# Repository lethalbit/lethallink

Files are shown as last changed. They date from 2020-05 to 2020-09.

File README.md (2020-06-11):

# lethallink

lethallink is a PCI-Express DMA engine with on board debugging machinery designed in an attempt to allow for mostly transparent access to a system under test with no software at all running on said system.

All of the information is exfiltrated onto a control system that can then be used for analysis. The control system can also interact with lethallink to add things like memory watchpoints via the control software or GDB integration. 

## Licenses

The lethallink project is licensed under 3 individual licenses, one for the hardware and gateware, one for the software and one for the documentation.

The hardware and gateware are licensed under the [CERN-OHL-S](https://ohwr.org/cern_ohl_s_v2.txt), the license for which can be found in [LICENSE.hardware](LICENSE.hardware) and [LICENSE.gateware](LICENSE.gateware).

The software is licensed under the BSD-3-Clause and can be found in [LICENSE.software](LICENSE.software).

The documentation is licensed under the Creative Commons [CC-BY-SA](https://creativecommons.org/licenses/by-sa/2.0/) and can be found in [LICENSE.docs](LICENSE.docs)

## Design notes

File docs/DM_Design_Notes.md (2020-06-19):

# Debug Module (DM) Daughtercard Design Notes

**NOTE:** These notes are the WIP version of the specification for lethallink Debug Module (DM) interface, for the version that is released and shipped for each revision of the board, consult the appropriate reference manual.

## Abstract

Do to the difficulty in providing an "all-in-one" solution that is flexible enough to allow to the low-level interfacing to machines, it has been decided that most of the architecture specific hardware to a daughtercard using a modified DDR4 SODIMM 260 pin format.

This allows for a substantial amount of IO and power to be provided to the daughtercard. Enabling a proper high-speed bus between the main system FPGA and any of the on-board machinery for data transport and a QSPI control channel for management and configuration.

## Electromechanical Specification

The electromechanical specification for the DM daughtercards follows much of normal specification for a DDR4 SODIMM with 260 positions, however it is longer and has a mounting hole for two `8mm` tall `M3` standoffs.

It's rough dimensions are `80mm` long by `69.60mm` wide, with the two `M3` mounting holes `4.5mm` from the side and bottom of each corner.

Below you can see a sketch of the profile for the daughtercards:

**NOTE:** This drawing is not to scale, for a to-scale drawing with all the measurements see the SolveSpace CAD files in the [`docs/cad/`](../docs/cad/) directory. Alternatively, you can inspect the [lethallink KiCad library](../docs/eda) where there is a footprint and schematic part. Or, lastly, use inspect one of the [debug modules](../hardware/boards), or use the [debug module template KiCad project](../hardware/boards/template_dm).

<p align="center">
  
</p>

### Pinout

The following is a table of the pinout for the debug module:

| PIN # | PIN NAME | PIN # | PIN NAME | PIN # | PIN NAME |
|---|---|---|---|---|---|
| `001` | `TODO NO SPEC` | `002` | `TODO NO SPEC` | `003` | `TODO NO SPEC` |
| `004` | `TODO NO SPEC` | `005` | `TODO NO SPEC` | `006` | `TODO NO SPEC` |
| `007` | `TODO NO SPEC` | `008` | `TODO NO SPEC` | `009` | `TODO NO SPEC` |
| `010` | `TODO NO SPEC` | `011` | `TODO NO SPEC` | `012` | `TODO NO SPEC` |
| `013` | `TODO NO SPEC` | `014` | `TODO NO SPEC` | `015` | `TODO NO SPEC` |
| `016` | `TODO NO SPEC` | `017` | `TODO NO SPEC` | `018` | `TODO NO SPEC` |
| `019` | `TODO NO SPEC` | `020` | `TODO NO SPEC` | `021` | `TODO NO SPEC` |
| `022` | `TODO NO SPEC` | `023` | `TODO NO SPEC` | `024` | `TODO NO SPEC` |
| `025` | `TODO NO SPEC` | `026` | `TODO NO SPEC` | `027` | `TODO NO SPEC` |
| `028` | `TODO NO SPEC` | `029` | `TODO NO SPEC` | `030` | `TODO NO SPEC` |
| `031` | `TODO NO SPEC` | `032` | `TODO NO SPEC` | `033` | `TODO NO SPEC` |
| `034` | `TODO NO SPEC` | `035` | `TODO NO SPEC` | `036` | `TODO NO SPEC` |
| `037` | `TODO NO SPEC` | `038` | `TODO NO SPEC` | `039` | `TODO NO SPEC` |
| `040` | `TODO NO SPEC` | `041` | `TODO NO SPEC` | `042` | `TODO NO SPEC` |
| `043` | `TODO NO SPEC` | `044` | `TODO NO SPEC` | `045` | `TODO NO SPEC` |
| `046` | `TODO NO SPEC` | `047` | `TODO NO SPEC` | `048` | `TODO NO SPEC` |
| `049` | `TODO NO SPEC` | `050` | `TODO NO SPEC` | `051` | `TODO NO SPEC` |
| `052` | `TODO NO SPEC` | `053` | `TODO NO SPEC` | `054` | `TODO NO SPEC` |
| `055` | `TODO NO SPEC` | `056` | `TODO NO SPEC` | `057` | `TODO NO SPEC` |
| `058` | `TODO NO SPEC` | `059` | `TODO NO SPEC` | `060` | `TODO NO SPEC` |
| `061` | `TODO NO SPEC` | `062` | `TODO NO SPEC` | `063` | `TODO NO SPEC` |
| `064` | `TODO NO SPEC` | `065` | `TODO NO SPEC` | `066` | `TODO NO SPEC` |
| `067` | `TODO NO SPEC` | `068` | `TODO NO SPEC` | `069` | `TODO NO SPEC` |
| `070` | `TODO NO SPEC` | `071` | `TODO NO SPEC` | `072` | `TODO NO SPEC` |
| `073` | `TODO NO SPEC` | `074` | `TODO NO SPEC` | `075` | `TODO NO SPEC` |
| `076` | `TODO NO SPEC` | `077` | `TODO NO SPEC` | `078` | `TODO NO SPEC` |
| `079` | `TODO NO SPEC` | `080` | `TODO NO SPEC` | `081` | `TODO NO SPEC` |
| `082` | `TODO NO SPEC` | `083` | `TODO NO SPEC` | `084` | `TODO NO SPEC` |
| `085` | `TODO NO SPEC` | `086` | `TODO NO SPEC` | `087` | `TODO NO SPEC` |
| `088` | `TODO NO SPEC` | `089` | `TODO NO SPEC` | `090` | `TODO NO SPEC` |
| `091` | `TODO NO SPEC` | `092` | `TODO NO SPEC` | `093` | `TODO NO SPEC` |
| `094` | `TODO NO SPEC` | `095` | `TODO NO SPEC` | `096` | `TODO NO SPEC` |
| `097` | `TODO NO SPEC` | `098` | `TODO NO SPEC` | `099` | `TODO NO SPEC` |
| `100` | `TODO NO SPEC` | `101` | `TODO NO SPEC` | `102` | `TODO NO SPEC` |
| `103` | `TODO NO SPEC` | `104` | `TODO NO SPEC` | `105` | `TODO NO SPEC` |
| `106` | `TODO NO SPEC` | `107` | `TODO NO SPEC` | `108` | `TODO NO SPEC` |
| `109` | `TODO NO SPEC` | `110` | `TODO NO SPEC` | `111` | `TODO NO SPEC` |
| `112` | `TODO NO SPEC` | `113` | `TODO NO SPEC` | `114` | `TODO NO SPEC` |
| `115` | `TODO NO SPEC` | `116` | `TODO NO SPEC` | `117` | `TODO NO SPEC` |
| `118` | `TODO NO SPEC` | `119` | `TODO NO SPEC` | `120` | `TODO NO SPEC` |
| `121` | `TODO NO SPEC` | `122` | `TODO NO SPEC` | `123` | `TODO NO SPEC` |
| `124` | `TODO NO SPEC` | `125` | `TODO NO SPEC` | `126` | `TODO NO SPEC` |
| `127` | `TODO NO SPEC` | `128` | `TODO NO SPEC` | `129` | `TODO NO SPEC` |
| `130` | `TODO NO SPEC` | `131` | `TODO NO SPEC` | `132` | `TODO NO SPEC` |
| `133` | `TODO NO SPEC` | `134` | `TODO NO SPEC` | `135` | `TODO NO SPEC` |
| `136` | `TODO NO SPEC` | `137` | `TODO NO SPEC` | `138` | `TODO NO SPEC` |
| `139` | `TODO NO SPEC` | `140` | `TODO NO SPEC` | `141` | `TODO NO SPEC` |
| `142` | `TODO NO SPEC` | `143` | `TODO NO SPEC` | `144` | `TODO NO SPEC` |
| `145` | `TODO NO SPEC` | `146` | `TODO NO SPEC` | `147` | `TODO NO SPEC` |
| `148` | `TODO NO SPEC` | `149` | `TODO NO SPEC` | `150` | `TODO NO SPEC` |
| `151` | `TODO NO SPEC` | `152` | `TODO NO SPEC` | `153` | `TODO NO SPEC` |
| `154` | `TODO NO SPEC` | `155` | `TODO NO SPEC` | `156` | `TODO NO SPEC` |
| `157` | `TODO NO SPEC` | `158` | `TODO NO SPEC` | `159` | `TODO NO SPEC` |
| `160` | `TODO NO SPEC` | `161` | `TODO NO SPEC` | `162` | `TODO NO SPEC` |
| `163` | `TODO NO SPEC` | `164` | `TODO NO SPEC` | `165` | `TODO NO SPEC` |
| `166` | `TODO NO SPEC` | `167` | `TODO NO SPEC` | `168` | `TODO NO SPEC` |
| `169` | `TODO NO SPEC` | `170` | `TODO NO SPEC` | `171` | `TODO NO SPEC` |
| `172` | `TODO NO SPEC` | `173` | `TODO NO SPEC` | `174` | `TODO NO SPEC` |
| `175` | `TODO NO SPEC` | `176` | `TODO NO SPEC` | `177` | `TODO NO SPEC` |
| `178` | `TODO NO SPEC` | `179` | `TODO NO SPEC` | `180` | `TODO NO SPEC` |
| `181` | `TODO NO SPEC` | `182` | `TODO NO SPEC` | `183` | `TODO NO SPEC` |
| `184` | `TODO NO SPEC` | `185` | `TODO NO SPEC` | `186` | `TODO NO SPEC` |
| `187` | `TODO NO SPEC` | `188` | `TODO NO SPEC` | `189` | `TODO NO SPEC` |
| `190` | `TODO NO SPEC` | `191` | `TODO NO SPEC` | `192` | `TODO NO SPEC` |
| `193` | `TODO NO SPEC` | `194` | `TODO NO SPEC` | `195` | `TODO NO SPEC` |
| `196` | `TODO NO SPEC` | `197` | `TODO NO SPEC` | `198` | `TODO NO SPEC` |
| `199` | `TODO NO SPEC` | `200` | `TODO NO SPEC` | `201` | `TODO NO SPEC` |
| `202` | `TODO NO SPEC` | `203` | `TODO NO SPEC` | `204` | `TODO NO SPEC` |
| `205` | `TODO NO SPEC` | `206` | `TODO NO SPEC` | `207` | `TODO NO SPEC` |
| `208` | `TODO NO SPEC` | `209` | `TODO NO SPEC` | `210` | `TODO NO SPEC` |
| `211` | `TODO NO SPEC` | `212` | `TODO NO SPEC` | `213` | `TODO NO SPEC` |
| `214` | `TODO NO SPEC` | `215` | `TODO NO SPEC` | `216` | `TODO NO SPEC` |
| `217` | `TODO NO SPEC` | `218` | `TODO NO SPEC` | `219` | `TODO NO SPEC` |
| `220` | `TODO NO SPEC` | `221` | `TODO NO SPEC` | `222` | `TODO NO SPEC` |
| `223` | `TODO NO SPEC` | `224` | `TODO NO SPEC` | `225` | `TODO NO SPEC` |
| `226` | `TODO NO SPEC` | `227` | `TODO NO SPEC` | `228` | `TODO NO SPEC` |
| `229` | `TODO NO SPEC` | `230` | `TODO NO SPEC` | `231` | `TODO NO SPEC` |
| `232` | `TODO NO SPEC` | `233` | `TODO NO SPEC` | `234` | `TODO NO SPEC` |
| `235` | `TODO NO SPEC` | `236` | `TODO NO SPEC` | `237` | `TODO NO SPEC` |
| `238` | `TODO NO SPEC` | `239` | `TODO NO SPEC` | `240` | `TODO NO SPEC` |
| `241` | `TODO NO SPEC` | `242` | `TODO NO SPEC` | `243` | `TODO NO SPEC` |
| `244` | `TODO NO SPEC` | `245` | `TODO NO SPEC` | `246` | `TODO NO SPEC` |
| `247` | `TODO NO SPEC` | `248` | `TODO NO SPEC` | `249` | `TODO NO SPEC` |
| `250` | `TODO NO SPEC` | `251` | `TODO NO SPEC` | `252` | `TODO NO SPEC` |
| `253` | `TODO NO SPEC` | `254` | `TODO NO SPEC` | `255` | `TODO NO SPEC` |
| `256` | `TODO NO SPEC` | `257` | `TODO NO SPEC` | `258` | `TODO NO SPEC` |
| `259` | `TODO NO SPEC` | `260` | `TODO NO SPEC` | | |

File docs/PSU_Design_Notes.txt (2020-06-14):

# ADP505 Based Supply Design Notes

Needed rails:
 * +1v2
 * +1v5
 * +1v8
 * +2v5

Freq: 700kHz ~~ 780kHz

Fsw = 750kHz

Rrt[kOhm] = (14288/750kHz)^1.081
Rrt ~ 25.16569kOhm Closest match is 24.9kOhm

Vref = 0v8
Vin = 12v0
Gm = 470μS

ΔVout_uv = ΔVout_ov = ΔVout_ripple = 0v05
Kuv = Kov = 2
ΔIstep = 0.5A

ΔIl = 15% * 2.5A For channels 1 and 2
ΔIl = 25% * 1.2A For channels 3 and 4

Ipeak = Iout + (ΔIl/2)
Irms = sqrt(Iout^2 + ((ΔIl^2)/Vin))

FBx Pin Formula:
	Vout = Vref * (1 + (Rtop/Rbot)) =
	Vout/Vref = 1 + (Rtop/Rbot)     =
	(Vout/Vref - 1) = Rtop / Rbot   =
	Rtop = (Vout/Vref - 1) * Rbot

Inductor Selection Formula:
	L = [(Vin - Vout) * D]/(ΔIl * Fsw)
	Where D = (Vout / Vin) and
	Where ΔIl = 15% * 2.5A || ΔIl = 15% * 1.2A  and
	Where Vin = 12v0 ∴ For channels 1 and 2
	L = [(Vin - Vout) * (Vout / Vin)]/((0.15 * 2.5A) * 750kHz) =
	L = [(12V - Vout) * (Vout / 12V)]/(0.375A * 750kHz)
	And ∴ For channels 3 and 4
	L = [(Vin - Vout) * (Vout / Vin)]/((0.25 * 1.2A) * 750kHz) =
	L = [(12V - Vout) * (Vout / 12V)]/(0.3A * 750kHz)

Output Capacitor Selection:
	Cout_ripple = (ΔIl)/(8 * Fsw * ΔVout_ripple)
	Resr = ΔVout_ripple/ΔIl

	Cout_uv = (Kuv * ΔIstep^2 * L)/(2*(Vin - Vout) * ΔVout_uv)
	Cout_ov = (Kov * ΔIstep^2 * L)/((Vout + ΔVout_ov)^2 - Vout^2)

Compensation Network Design:
	Fc = Fsw / 10 = 750kHz / 10 = 75kHz
	Rc = (2 * π * Vout * Cout * Fc) / (0.8V * Gm * Avi)
	Where Avi = 10A/V || Avi = 3.33A/V and
	Where Gm = 470μS ∴ for channels 1 and 2
	Rc = (2 * π * Vout * Cout * Fc) / (0.8V * 470μS * 10A/V)
	And ∴ for channels 2 and 4
	Rc = (2 * π * Vout * Cout * Fc) / (0.8V * 470μS * 3.33A/V)

	Cc = ((R + Resr) * Cout) / Rc)
	Ccp = (Resr * Cout) / Rc

Channel 1 (1v2):
	Rilim1 = Float (4.4A Peak I) [Pin DL1 / 31]
	FB1 Resistors:
		Rtop: 5kOhm
		Rbot: 10kOhm
	Li ~ 3.84μH
	Ipeak = 2.6875A
	Irms = 2.5A

	Inductor: XFL4020-332MEC
		L = 3.3μH
		Isat = 2.9A
		Irms = 5.2A
		DCR = 38.3mOhm

	Output Cap: C1206C226K9PACTU
		Cout_ripple = 1.25μF
		Resr = 133.3333mOhm
		Cout_uv = 1.527777μF
		Cout_ov = 13.46938μF

		Required Capacitance >= 13.5μF X5R
		Actual: 22μF X5R

	Compensation Network:
		Rc ~ 3.308698kOhm = 3.3kOhm [CRCW06033K30FKEAHP]
		Cc ~ 2.006666nF = 2.2nF [C0603C222J3RACTU]
		Ccp ~ 6.666666pF = 10pF [C0603C100K5RAC7867]

Channel 2 (1v5):
	Rilim2 = Float (4.4A Peak I) [Pin DL2 / 29]
	FB1: Resistors:
		Rtop: 8.75kOhm
		Rbot: 10kOhm
	Li ~ 4.666666μH
	Ipeak = 2.6875A
	Irms = 2.5A

	Inductor: XFL4020-472MEC
		L = 4.7μH
		Isat = 2.7A
		Irms = 5A
		DCR = 52.2mOhm

	Output Cap: C1206C226K9PACTU
		Cout_ripple = 1.25μF
		Resr = 133.3333mOhm
		Cout_uv = 2.238095μF
		Cout_ov = 15.40983μF

		Required Capacitance >= 15.5μF X5R
		Actual: 22μF X5R

	Compensation Network:
		Rc ~ 4.135873kOhm = 4.22kOhm [CRCW06034K22FKEAHP]
		Cc ~ 1.569194nF = 1.8nF [C0603C182J5RACTU]
		Ccp ~ 5.213270pF = 10pF [C0603C100K5RAC7867]

Channel 3 (1v8):
	FB1: Resistors:
		Rtop: 12.5kOhm
		Rbot: 10kOhm
	Li ~ 6.8μH
	Ipeak = 1.35A
	Irms = 1.20312A

	Inductor: XAL4030-682MEC
		L = 6.8μH
		Isat = 3.6A
		Irms = 3.9A
		DCR = 67.4mOhm

	Output Cap: C1206C226K9PACTU
		Cout_ripple = 1μF
		Resr = 166.6666mOhm
		Cout_uv = 3.333333μF
		Cout_ov = 18.63013μF

		Required Capacitance >= 19μF X5R
		Actual: 22μF X5R

	Compensation Network:
		Rc ~ 14.90404kOhm = 15kOhm [CRCW060315K0FKEAHP]
		Cc ~ 441.4666pF = 470pF [C0603C471J5RACTU]
		Ccp ~ 1.466666pF = 10pF [C0603C100K5RAC7867]

Channel 4 (2v5):
	FB1: Resistors:
		Rtop: 21.25kOhm
		Rbot: 10kOhm
	Li ~ 8.796296μH
	Ipeak = 1.35A
	Irms = 1.20312A

	Inductor: XAL4040-822MEC
		L = 8.2μH
		Isat = 3.4A
		Irms =
		DCR = 66.9mOhm

	Output Cap: C1206C226K9PACTU
		Cout_ripple = 1μF
		Resr = 166.6666mOhm
		Cout_uv = 4.315789μF
		Cout_ov = 16.23762μF

		Required Capacitance >= 16.5μF X5R
		Actual: 22μF X5R

	Compensation Network:
		Rc ~ 20.70006kOhm = 21kOhm [CRCW060321K0FKEAHP]
		Cc ~ 315.3333pF = 330pF [C0603C331J5RACTU]
		Ccp ~ 1.047619pF = 10pF [C0603C100K5RAC7867]

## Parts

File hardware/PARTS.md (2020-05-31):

# MCU's an additional IC's

 * LFE5UM5G-85F-8BG381I - Main FPGA (w/ RISC-V Supervisory soft-core)
 * MT25QL512ABB1EW9-0SIT - Bitstream / Firmware Flash
 * MT52L256M32D1PF-107 WT:B - LPDDR3 Cache

 * Exfil / Control
   * PI90LV179? x4
   * DS90UB947-Q1?
   * DS92LV16TVHG/NOPB ?
   * Connector - Molex 0855437001

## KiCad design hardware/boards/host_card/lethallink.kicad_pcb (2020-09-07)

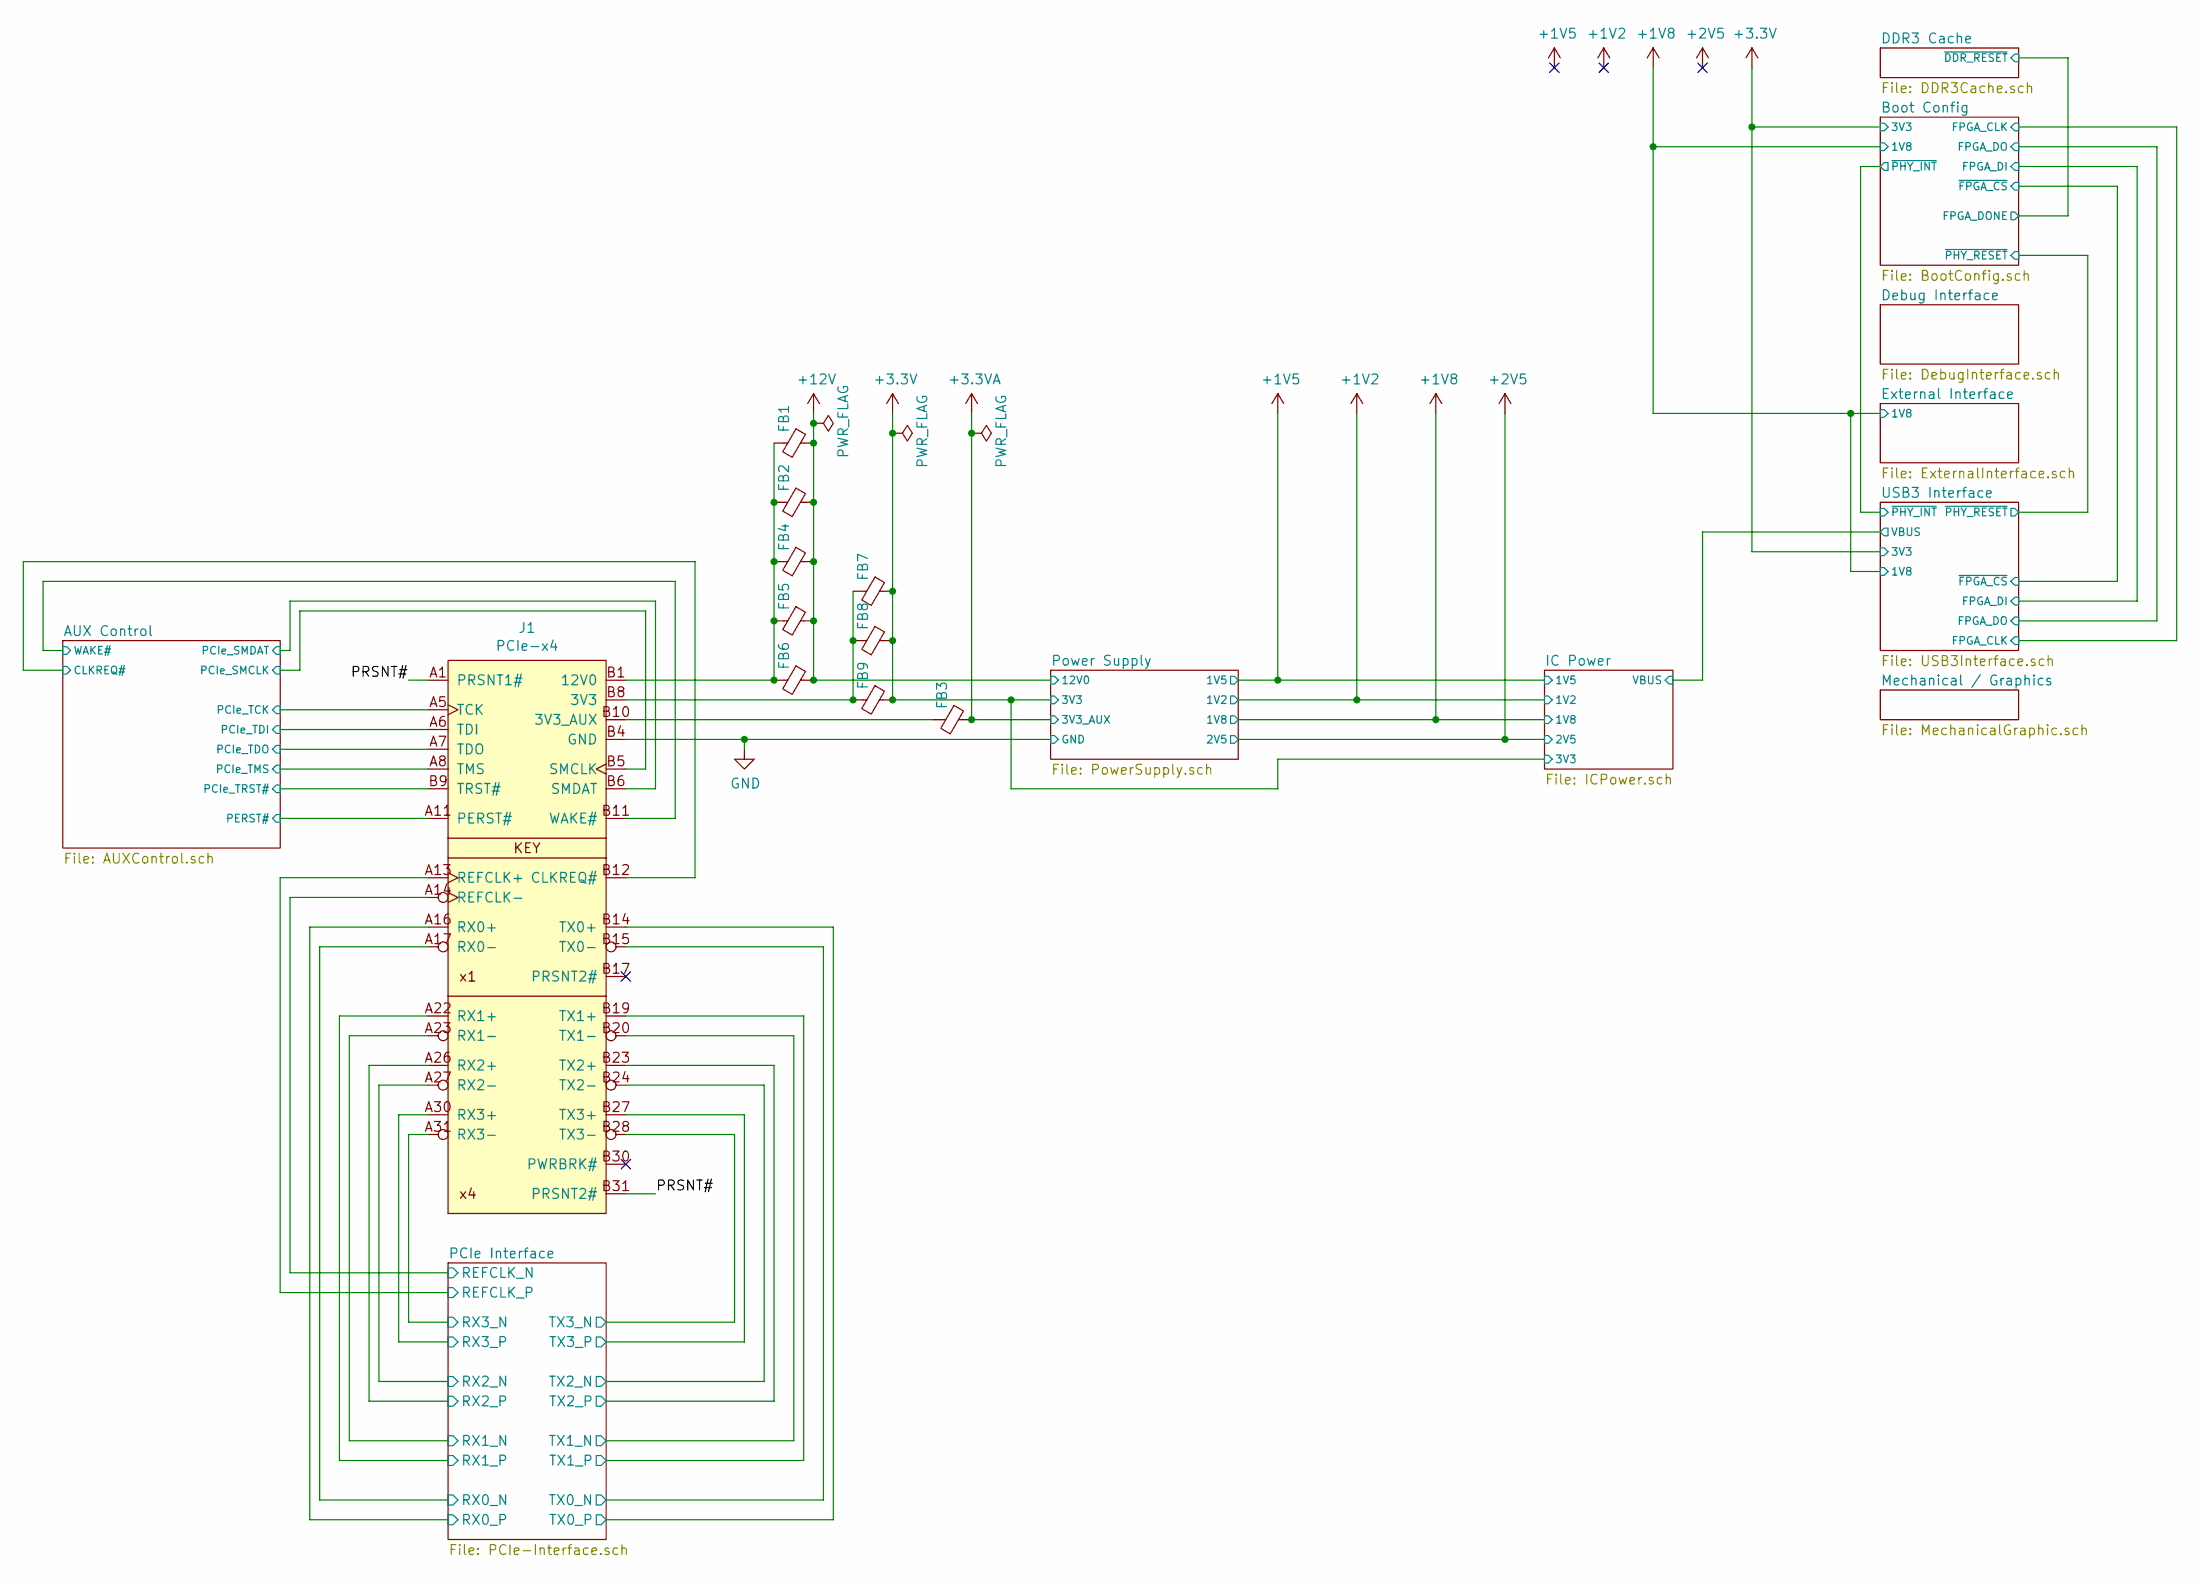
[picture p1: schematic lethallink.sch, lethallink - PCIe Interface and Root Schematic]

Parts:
FB1, FB2, FB3, FB4, FB5, FB6, FB7, FB8, FB9: 33 @ 100Mhz; R_0402_1005Metric; MPN BLM15PX330SN1D
J1: PCIe-x4; PCIe-x4-Card-FH

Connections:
+3.3VA: FB3.1; also elsewhere on the board
+3V3: FB7.1, FB8.1, FB9.1; also elsewhere on the board
+12V: FB1.1, FB2.1, FB4.1, FB5.1, FB6.1; also elsewhere on the board
/AUX Control/CLKREQ#: J1.B12 (CLKREQ#); also elsewhere on the board
/AUX Control/PCIe_SMCLK: J1.B5 (SMCLK); also elsewhere on the board
/AUX Control/PCIe_SMDAT: J1.B6 (SMDAT); also elsewhere on the board
/AUX Control/PCIe_TCK: J1.A5 (TCK); also elsewhere on the board
/AUX Control/PCIe_TDI: J1.A6 (TDI); also elsewhere on the board
/AUX Control/PCIe_TDO: J1.A7 (TDO); also elsewhere on the board
/AUX Control/PCIe_TMS: J1.A8 (TMS); also elsewhere on the board
/AUX Control/PCIe_TRST#: J1.B9 (TRST#); also elsewhere on the board
/AUX Control/PERST#: J1.A11 (PERST#); also elsewhere on the board
/AUX Control/WAKE#: J1.B11 (WAKE#); also elsewhere on the board
/PCIe Interface/REFCLK_N: J1.A14 (REFCLK-); also elsewhere on the board
/PCIe Interface/REFCLK_P: J1.A13 (REFCLK+); also elsewhere on the board
/PCIe Interface/RX0_N: J1.A17 (RX0-); also elsewhere on the board
/PCIe Interface/RX0_P: J1.A16 (RX0+); also elsewhere on the board
/PCIe Interface/RX1_N: J1.A23 (RX1-); also elsewhere on the board
/PCIe Interface/RX1_P: J1.A22 (RX1+); also elsewhere on the board
/PCIe Interface/RX2_N: J1.A27 (RX2-); also elsewhere on the board
/PCIe Interface/RX2_P: J1.A26 (RX2+); also elsewhere on the board
/PCIe Interface/RX3_N: J1.A31 (RX3-); also elsewhere on the board
/PCIe Interface/RX3_P: J1.A30 (RX3+); also elsewhere on the board
/PCIe Interface/TX0_N: J1.B15 (TX0-); also elsewhere on the board
/PCIe Interface/TX0_P: J1.B14 (TX0+); also elsewhere on the board
/PCIe Interface/TX1_N: J1.B20 (TX1-); also elsewhere on the board
/PCIe Interface/TX1_P: J1.B19 (TX1+); also elsewhere on the board
/PCIe Interface/TX2_N: J1.B24 (TX2-); also elsewhere on the board
/PCIe Interface/TX2_P: J1.B23 (TX2+); also elsewhere on the board
/PCIe Interface/TX3_N: J1.B28 (TX3-); also elsewhere on the board
/PCIe Interface/TX3_P: J1.B27 (TX3+); also elsewhere on the board
/PRSNT#: J1.A1 (PRSNT1#), J1.B31 (PRSNT2#)
GND: J1.A4 (GND), J1.A12 (GND), J1.A15 (GND), J1.A18 (GND), J1.A20 (GND), J1.A21 (GND), J1.A24 (GND), J1.A25 (GND), J1.A28 (GND), J1.A29 (GND), J1.A32 (GND), J1.B4 (GND), J1.B7 (GND), J1.B13 (GND), J1.B16 (GND), J1.B18 (GND), J1.B21 (GND), J1.B22 (GND), J1.B25 (GND), J1.B26 (GND), J1.B29 (GND), J1.B32 (GND), J1.G1 (GND), J1.G2 (GND); also elsewhere on the board
unnamed: FB1.2, FB2.2, FB4.2, FB5.2, FB6.2, J1.A2 (12V0), J1.A3 (12V0), J1.B1 (12V0), J1.B2 (12V0), J1.B3 (12V0)
unnamed: FB3.2, J1.B10 (3V3_AUX)
unnamed: FB7.2, FB8.2, FB9.2, J1.A9 (3V3), J1.A10 (3V3), J1.B8 (3V3)

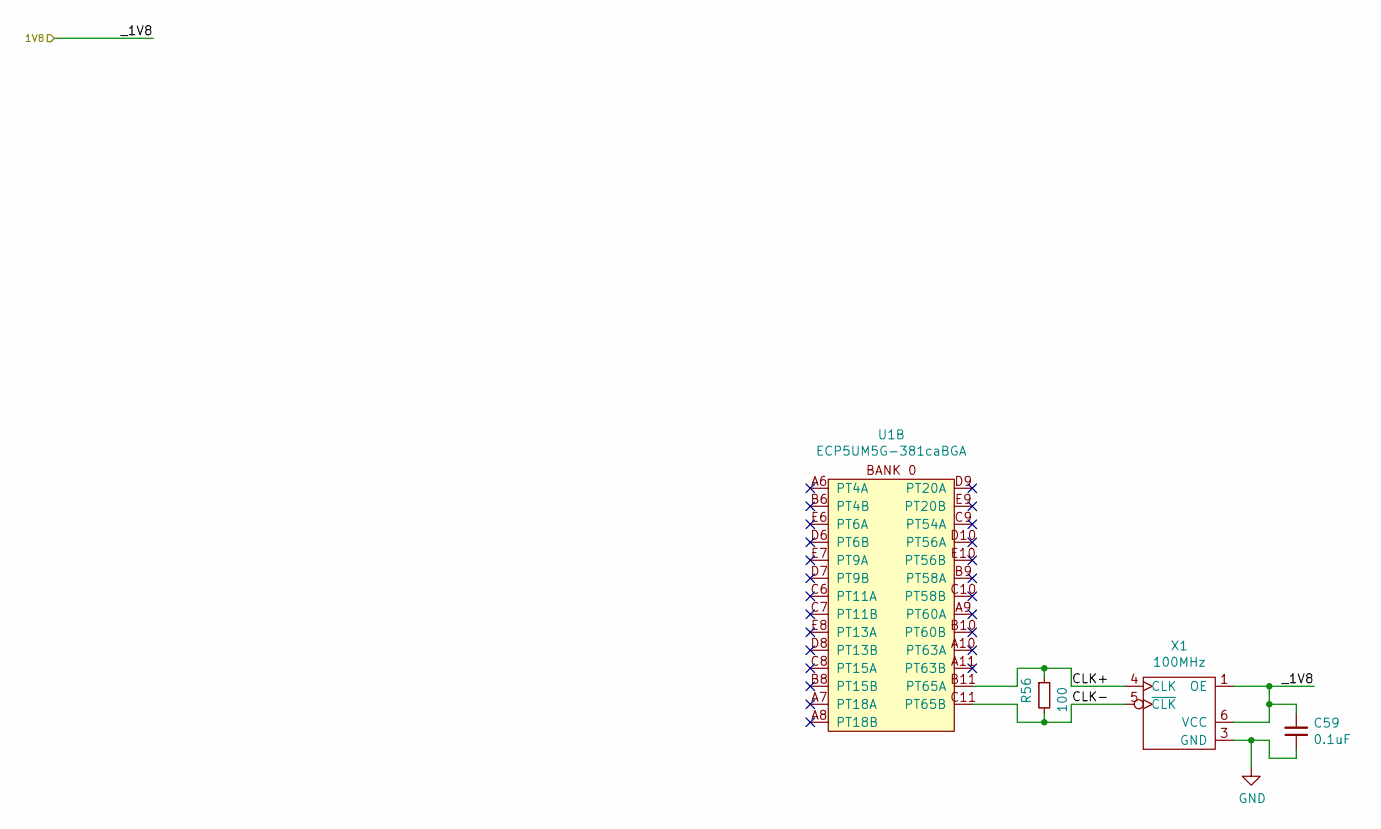
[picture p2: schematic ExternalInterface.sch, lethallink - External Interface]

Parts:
C59: 0.1uF; C_0603_1608Metric; MPN C0603C104M5RACTU
R56: 100; R_0402_1005Metric; MPN RCS0402100RFKED
U1: ECP5UM5G-381caBGA; 318caBGA; MPN LFE5UM5G-85F-8BG381I; DIGIKEY_PN 220-2112-ND
X1: 100MHz; AX3; MPN AX3DCF1-100.0000

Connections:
+1V8: C59.2, X1.1 (OE), X1.6 (VCC); also elsewhere on the board
/External Interface/CLK+: R56.1, U1.B11 (PT65A), X1.4 (CLK)
/External Interface/CLK-: R56.2, U1.C11 (PT65B), X1.5 (~CLK)
GND: C59.1, X1.3 (GND); also elsewhere on the board

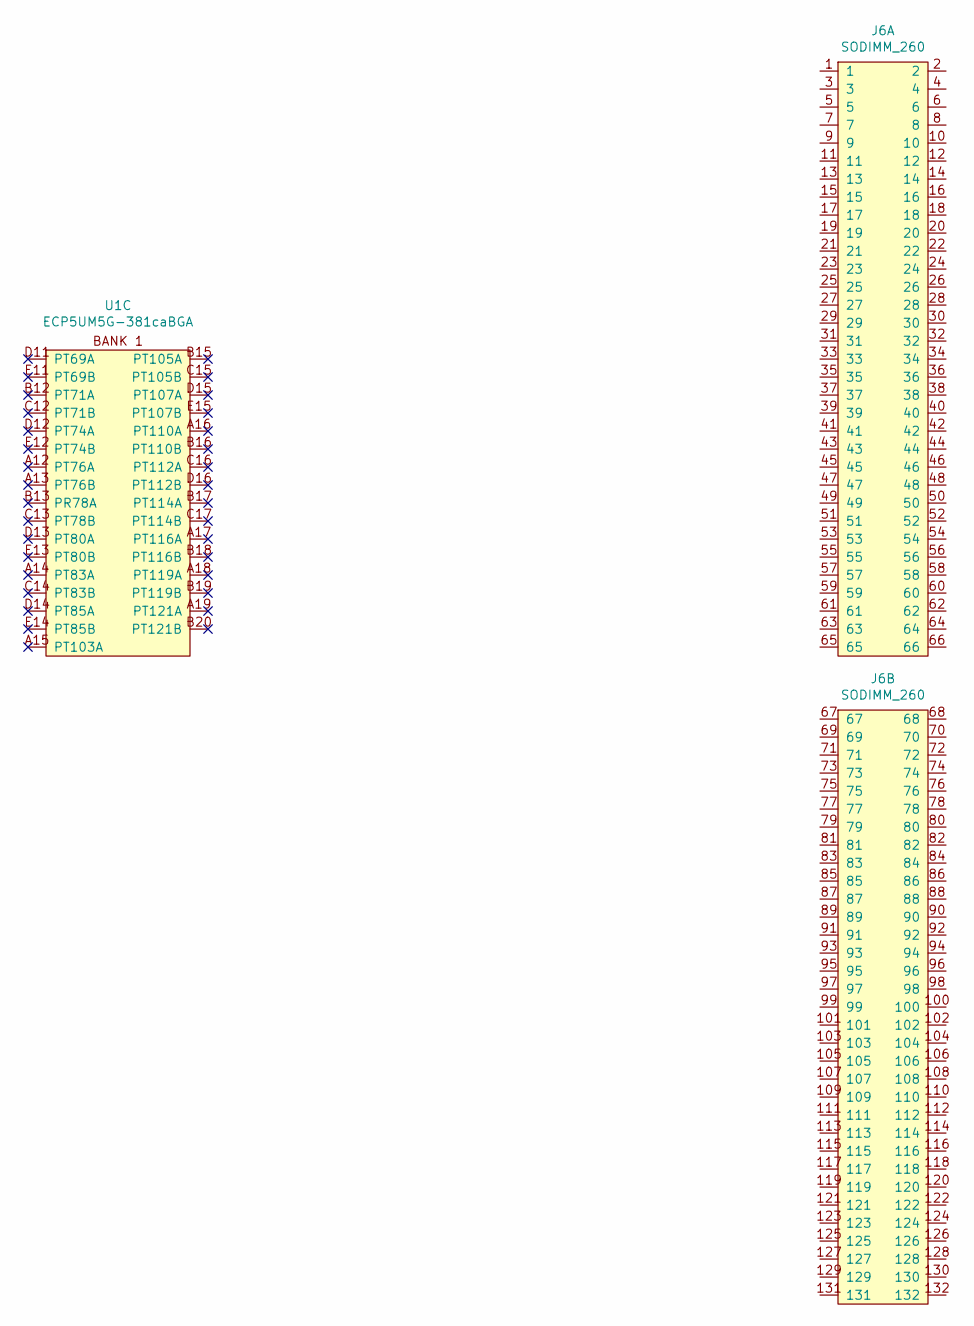
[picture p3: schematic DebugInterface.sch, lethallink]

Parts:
J6: SODIMM_260; lethallink_debug_module_mount; MPN 2309413-1
U1: ECP5UM5G-381caBGA; 318caBGA; MPN LFE5UM5G-85F-8BG381I; DIGIKEY_PN 220-2112-ND

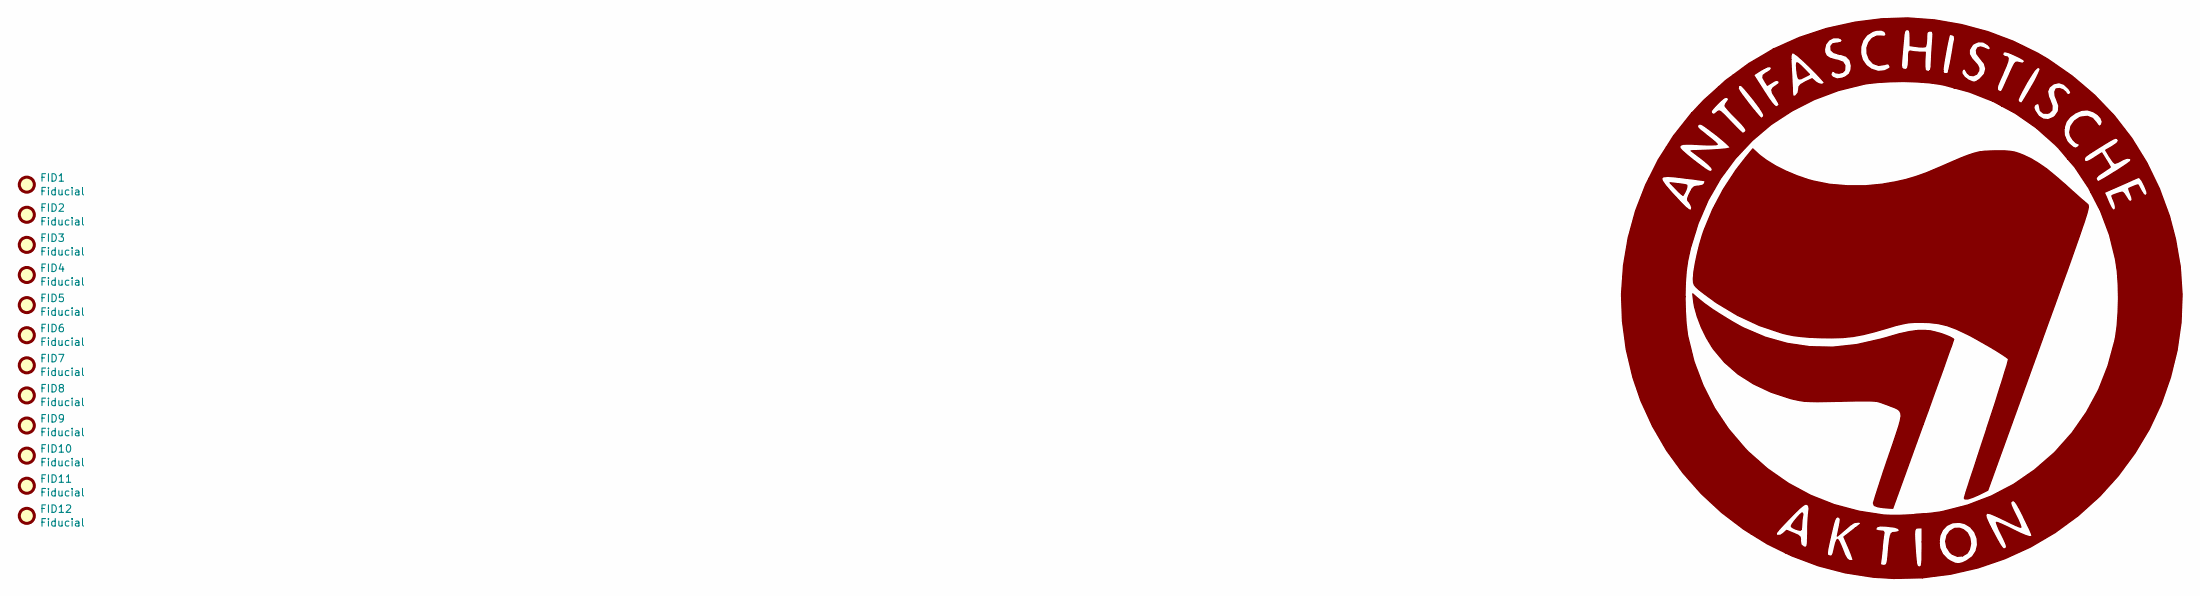
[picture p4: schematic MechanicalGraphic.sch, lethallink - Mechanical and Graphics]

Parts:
FID1, FID2, FID3, FID4, FID5, FID6, FID7, FID8, FID9, FID10, FID11, FID12: Fiducial; Fiducial_0.5mm_Mask1mm
G1: Antifaschistische_Aktion; Antifaschistische Aktion_100dpi

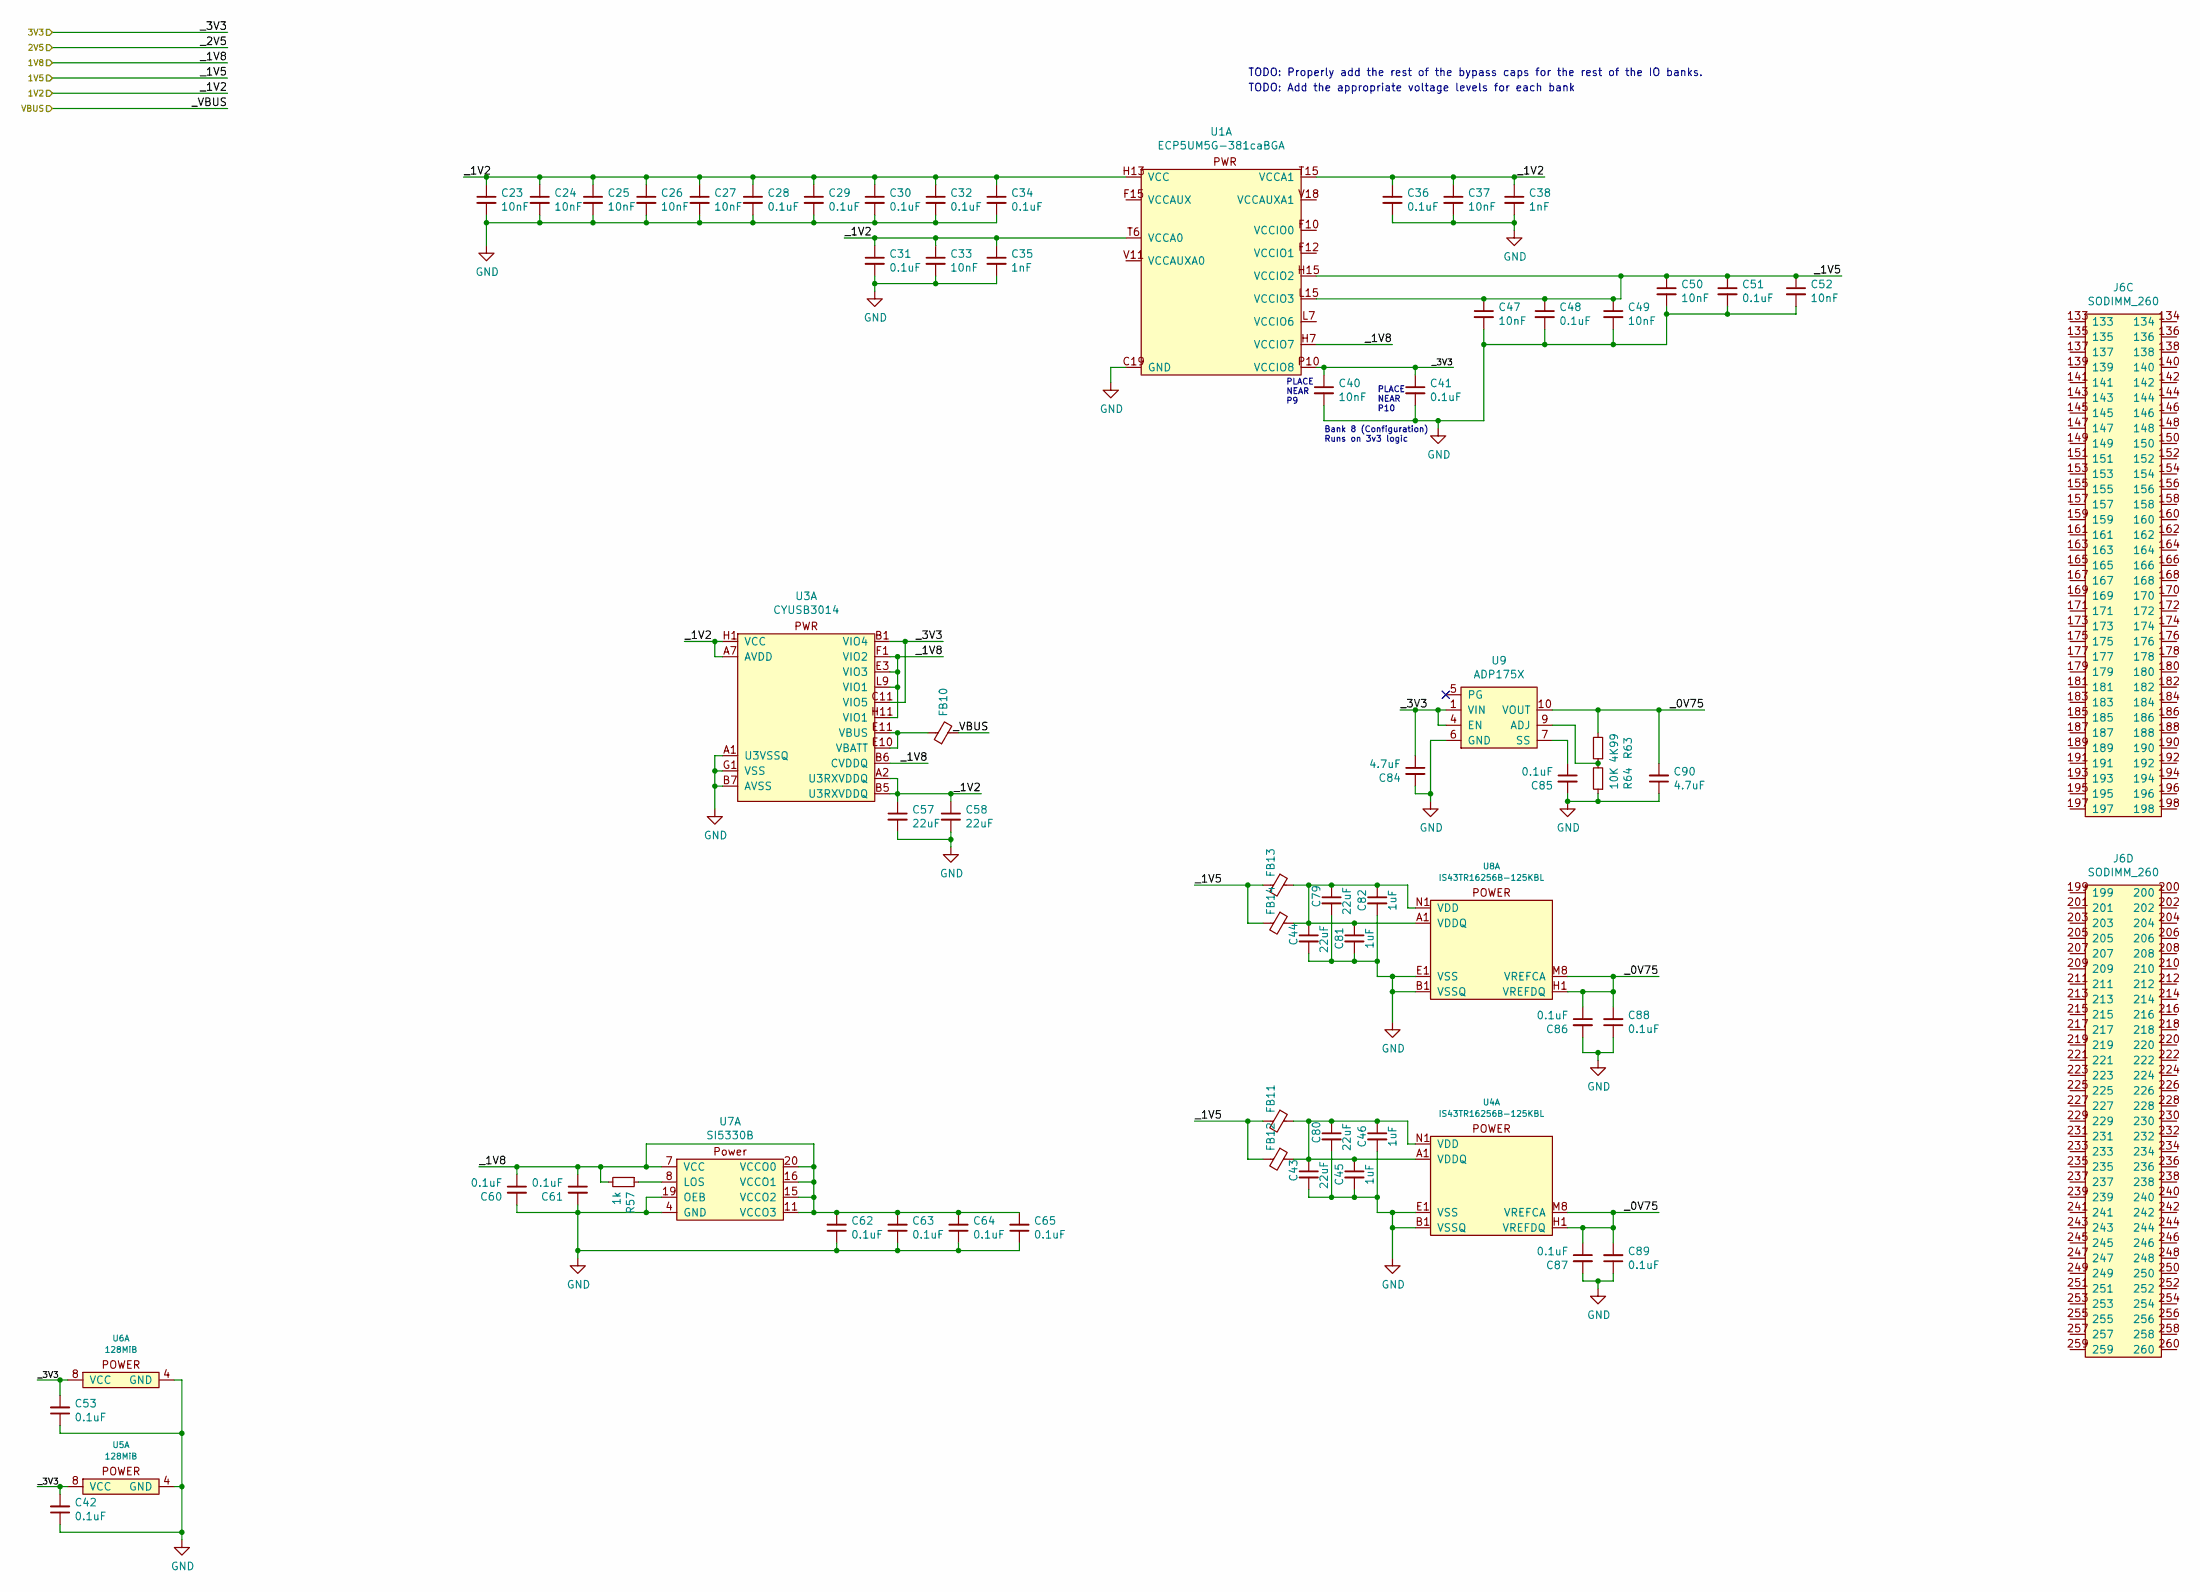
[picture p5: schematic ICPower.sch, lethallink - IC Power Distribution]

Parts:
C23, C24, C25, C26, C27, C33, C37, C40, C47, C49, C50, C52: 10nF; C_0402_1005Metric; MPN C0402C103M5RACTU
C28, C29, C30, C31, C32, C34, C36, C41, C48, C51: 0.1uF; C_0402_1005Metric; MPN C0402C104M8PACTU
C35, C38: 1nF; C_0402_1005Metric; MPN C0402C102K5RACTU
C42, C53, C60, C61, C62, C63, C64, C65, C85, C86, C87, C88, C89: 0.1uF; C_0603_1608Metric; MPN C0603C104M5RACTU
C43, C44, C79, C80: 22uF; C_0805_2012Metric; MPN C0805C226K9PAC7800
C45, C46, C81, C82: 1uF; C_0603_1608Metric; MPN C0603C105K4RACTU
C57, C58: 22uF; C_0805_2012Metric; MPN C0805C226M9PACTU
C84, C90: 4.7uF; C_0603_1608Metric; MPN C0603C475K8PACTU
FB10, FB11, FB12, FB13, FB14: 220 @ 100Mhz; R_0603_1608Metric; MPN BLM18AG221SN1D
J6: SODIMM_260; lethallink_debug_module_mount; MPN 2309413-1
R57: 1k; R_0603_1608Metric; MPN CRCW06031K00FKEAHP
R63: 4K99; R_0603_1608Metric; MPN CRCW06034K99FKEAC
R64: 10K; R_0603_1608Metric; MPN RCS060310K0FKEA
U1: ECP5UM5G-381caBGA; 318caBGA; MPN LFE5UM5G-85F-8BG381I; DIGIKEY_PN 220-2112-ND
U3: CYUSB3014; BGA-121_11x11_10.0x10.0mm; MPN CYUSB3014-BZXI; DIGIKEY_PN 428-3130-ND
U4, U8: IS43TR16256B-125KBL; BGA-96_9.0x13.0mm_Layout2x3x16_P0.8mm; MPN IS43TR16256B-125KBL
U5: 128MiB; WSON-8-1EP-6.0x8.0mm; MPN W25N01GVZEIG TR
U6: 128MiB; WSON-8-1EP-6.0x8.0mm; MPN W25N01GVZEIG
U7: SI5330B; VQFN-24-1EP_4x4mm_P0.5mm_EP2.45x2.45mm; MPN SI5330B-B00205-GM
U9: ADP175X; QFN-16-1EP_4x4mm_P0.65mm_EP2.5x2.5mm; MPN ADP1753

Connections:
+1V2: C23.1, C24.1, C25.1, C26.1, C27.1, C28.1, C29.1, C30.1, C31.1, C32.1, C33.1, C34.1, C35.1, C36.1, C37.1, C38.1, C57.1, C58.1, U1.H8 (VCC), U1.H9 (VCC), U1.H10 (VCC), U1.H11 (VCC), U1.H12 (VCC), U1.H13 (VCC), U1.J8 (VCC), U1.J13 (VCC), U1.K8 (VCC), U1.K13 (VCC), U1.L8 (VCC), U1.L13 (VCC), U1.M8 (VCC), U1.M13 (VCC), U1.N8 (VCC), U1.N9 (VCC), U1.N10 (VCC), U1.N11 (VCC), U1.N12 (VCC), U1.N13 (VCC), U1.T6 (VCCA0), U1.T15 (VCCA1), U1.U6 (VCCA0), U1.U15 (VCCA1), U3.A2 (U3RXVDDQ), U3.A7 (AVDD), U3.B5 (U3RXVDDQ), U3.B10 (VCC), U3.C3 (VCC), U3.E9 (VCC), U3.F11 (VCC), U3.H1 (VCC), U3.J11 (VCC), U3.L5 (VCC), U3.L7 (VCC); also elsewhere on the board
+1V5: C47.1, C48.1, C49.1, C50.1, C51.1, C52.1, FB11.2, FB12.2, FB13.2, FB14.2, U1.H14 (VCCIO2), U1.H15 (VCCIO2), U1.J15 (VCCIO2), U1.L14 (VCCIO3), U1.L15 (VCCIO3), U1.M15 (VCCIO3); also elsewhere on the board
+1V8: C60.1, C61.1, C62.2, C63.2, C64.2, C65.2, R57.2, U1.H6 (VCCIO7), U1.H7 (VCCIO7), U1.J6 (VCCIO7), U3.B6 (CVDDQ), U3.E3 (VIO3), U3.F1 (VIO2), U3.H11 (VIO1), U3.L9 (VIO1), U7.7 (VCC), U7.11 (VCCO3), U7.15 (VCCO2), U7.16 (VCCO1), U7.20 (VCCO0), U7.24 (VCC); also elsewhere on the board
+3V3: C40.1, C41.1, C42.2, C53.2, C84.1, U1.P9 (VCCIO8), U1.P10 (VCCIO8), U3.B1 (VIO4), U3.C11 (VIO5), U5.8 (VCC), U6.8 (VCC), U9.1 (VIN), U9.2 (VIN), U9.3 (VIN), U9.4 (EN), U9.15 (VIN), U9.16 (VIN); also elsewhere on the board
/IC Power/VBUS: FB10.2; also elsewhere on the board
/IC Power/_0V75: C86.1, C87.1, C88.2, C89.2, C90.2, R63.2, U4.H1 (VREFDQ), U4.M8 (VREFCA), U8.H1 (VREFDQ), U8.M8 (VREFCA), U9.10 (VOUT), U9.11 (VOUT), U9.12 (VOUT), U9.13 (VOUT), U9.14 (VOUT)
GND: C23.2, C24.2, C25.2, C26.2, C27.2, C28.2, C29.2, C30.2, C31.2, C32.2, C33.2, C34.2, C35.2, C36.2, C37.2, C38.2, C40.2, C41.2, C42.1, C43.2, C44.2, C45.2, C46.2, C47.2, C48.2, C49.2, C50.2, C51.2, C52.2, C53.1, C57.2, C58.2, C60.2, C61.2, C62.1, C63.1, C64.1, C65.1, C79.2, C80.2, C81.2, C82.2, C84.2, C85.2, C86.2, C87.2, C88.1, C89.1, C90.1, R64.1, U1.B7 (GND), U1.B14 (GND), U1.C19 (GND), U1.D4 (GND), U1.F7 (GND), U1.F8 (GND), U1.F13 (GND), U1.F14 (GND), U1.G4 (GND), U1.G6 (GND), U1.G7 (GND), U1.G8 (GND), U1.G9 (GND), U1.G10 (GND), U1.G11 (GND), U1.G12 (GND), U1.G13 (GND), U1.G14 (GND), U1.G15 (GND), U1.G17 (GND), U1.H19 (GND), U1.J2 (GND), U1.J7 (GND), U1.J9 (GND), U1.J10 (GND), U1.J11 (GND), U1.J12 (GND), U1.J14 (GND), U1.K6 (GND), U1.K7 (GND), U1.K9 (GND), U1.K10 (GND), U1.K11 (GND), U1.K12 (GND), U1.K14 (GND), U1.K15 (GND), U1.L9 (GND), U1.L10 (GND), U1.L11 (GND), U1.L12 (GND), U1.M2 (GND), U1.M7 (GND), U1.M9 (GND), U1.M10 (GND), U1.M11 (GND), U1.M12 (GND), U1.M14 (GND), U1.M16 (GND), U1.N6 (GND), U1.N7 (GND), U1.N14 (GND), U1.N15 (GND), U1.P7 (GND), U1.P8 (GND), U1.P11 (GND), U1.P12 (GND), U1.P13 (GND), U1.P14 (GND), U1.R19 (GND), U1.U7 (GND), U1.U8 (GND), U1.U9 (GND), U1.U10 (GND), U1.U11 (GND), U1.U12 (GND), U1.U13 (GND), U1.U14 (GND), U1.V5 (GND), U1.V6 (GND), U1.V7 (GND), U1.V8 (GND), U1.V9 (GND), U1.V12 (GND), U1.V13 (GND), U1.V14 (GND), U1.V15 (GND), U1.V16 (GND), U1.V19 (GND), U1.V20 (GND), U1.W6 (GND), U1.W7 (GND), U1.W12 (GND), U1.W15 (GND), U1.W16 (GND), U1.W19 (GND), U3.A1 (U3VSSQ), U3.A8 (VSS), U3.B7 (AVSS), U3.B8 (VSS), U3.B9 (VSS), U3.D8 (VSS), U3.E2 (VSS), U3.G1 (VSS), U3.G11 (VSS), U3.K3 (VSS), U3.K4 (VSS), U3.L1 (VSS), U3.L2 (VSS), U3.L3 (VSS), U3.L6 (VSS), U3.L11 (VSS), U4.A9 (VSS), U4.B1 (VSSQ), U4.B3 (VSS), U4.B9 (VSSQ), U4.D1 (VSSQ), U4.D8 (VSSQ), U4.E1 (VSS), U4.E2 (VSSQ), U4.E8 (VSSQ), U4.F9 (VSSQ), U4.G1 (VSSQ), U4.G8 (VSS), U4.G9 (VSSQ), U4.J2 (VSS), U4.J8 (VSS), U4.M1 (VSS), U4.M9 (VSS), U4.P1 (VSS), U4.P9 (VSS), U4.T1 (VSS), U4.T9 (VSS), U5.4 (GND), U5.9 (GND), U6.4 (GND), U6.9 (GND), U7.4 (GND), U7.5 (GND), U7.6 (GND), U7.12 (GND), U7.19 (OEB), U7.23 (GND), U7.25 (GND), U8.A9 (VSS), U8.B1 (VSSQ), U8.B3 (VSS), U8.B9 (VSSQ), U8.D1 (VSSQ), U8.D8 (VSSQ), U8.E1 (VSS), U8.E2 (VSSQ), U8.E8 (VSSQ), U8.F9 (VSSQ), U8.G1 (VSSQ), U8.G8 (VSS), U8.G9 (VSSQ), U8.J2 (VSS), U8.J8 (VSS), U8.M1 (VSS), U8.M9 (VSS), U8.P1 (VSS), U8.P9 (VSS), U8.T1 (VSS), U8.T9 (VSS), U9.6 (GND), U9.17 (GND); also elsewhere on the board
unnamed: C43.1, C45.1, C46.1, C80.1, FB11.1, FB12.1, U4.A1 (VDDQ), U4.A8 (VDDQ), U4.B2 (VDD), U4.C1 (VDDQ), U4.C9 (VDDQ), U4.D2 (VDDQ), U4.D9 (VDD), U4.E9 (VDDQ), U4.F1 (VDDQ), U4.G7 (VDD), U4.H2 (VDDQ), U4.H9 (VDDQ), U4.K2 (VDD), U4.K8 (VDD), U4.N1 (VDD), U4.N9 (VDD), U4.R1 (VDD), U4.R9 (VDD)
unnamed: C44.1, C79.1, C81.1, C82.1, FB13.1, FB14.1, U8.A1 (VDDQ), U8.A8 (VDDQ), U8.B2 (VDD), U8.C1 (VDDQ), U8.C9 (VDDQ), U8.D2 (VDDQ), U8.D9 (VDD), U8.E9 (VDDQ), U8.F1 (VDDQ), U8.G7 (VDD), U8.H2 (VDDQ), U8.H9 (VDDQ), U8.K2 (VDD), U8.K8 (VDD), U8.N1 (VDD), U8.N9 (VDD), U8.R1 (VDD), U8.R9 (VDD)
unnamed: C85.1, U9.7 (SS)
unnamed: FB10.1, U3.E10 (VBATT), U3.E11 (VBUS)
unnamed: R57.1, U7.8 (LOS)
unnamed: R63.1, R64.2, U9.9 (ADJ)
unnamed: U1.F9 (VCCIO0), U1.F10 (VCCIO0)
unnamed: U1.F11 (VCCIO1), U1.F12 (VCCIO1)
unnamed: U1.F6 (VCCAUX), U1.F15 (VCCAUX), U1.P6 (VCCAUX), U1.P15 (VCCAUX)
unnamed: U1.L6 (VCCIO6), U1.L7 (VCCIO6), U1.M6 (VCCIO6)
unnamed: U1.V10 (VCCAUXA0), U1.V11 (VCCAUXA0)
unnamed: U1.V17 (VCCAUXA1), U1.V18 (VCCAUXA1)

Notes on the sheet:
PLACE NEAR P9
PLACE NEAR P10
Bank 8 (Configuration) Runs on 3v3 logic
TODO: Properly add the rest of the bypass caps for the rest of the IO banks.
TODO: Add the appropriate voltage levels for each bank

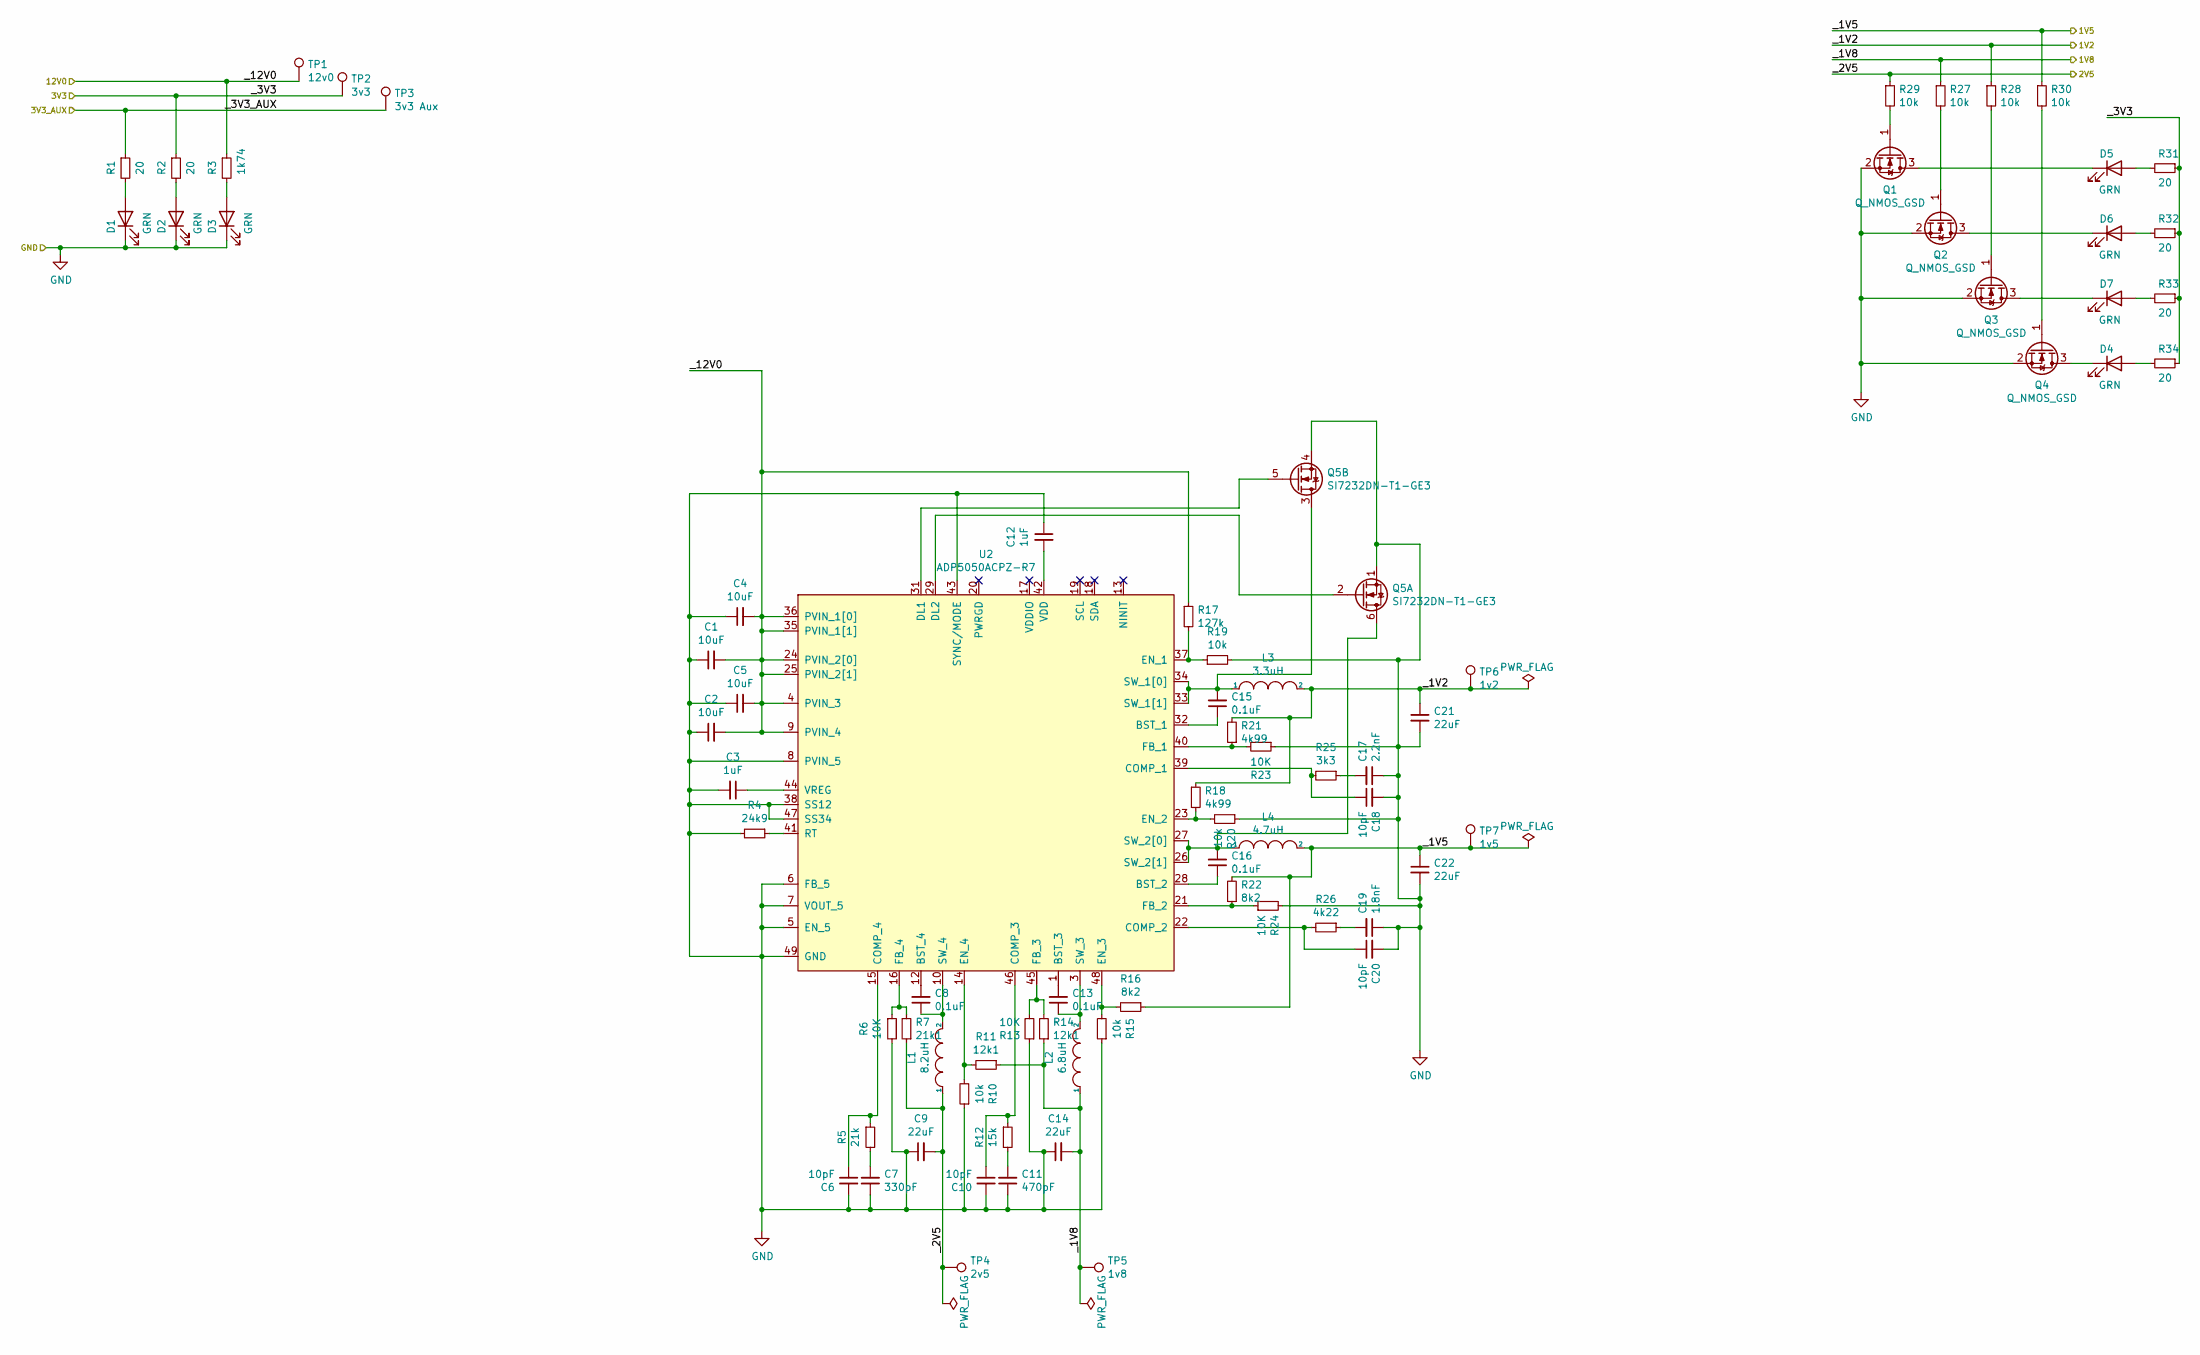
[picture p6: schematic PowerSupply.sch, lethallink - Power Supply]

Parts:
C1, C2, C4, C5: 10uF; C_1206_3216Metric; MPN C1206C106K3PACTU
C3, C12: 1uF; C_0603_1608Metric; MPN C0603C105K4RACTU
C6, C10, C18, C20: 10pF; C_0603_1608Metric; MPN C0603C100K5RAC7867
C7: 330pF; C_0603_1608Metric; MPN C0603C331J5RACTU
C8, C13, C15, C16: 0.1uF; C_0603_1608Metric; MPN C0603C104M5RACTU
C9, C14, C21, C22: 22uF; C_1206_3216Metric; MPN C1206C226K9PACTU
C11: 470pF; C_0603_1608Metric; MPN C0603C471J5RACTU
C17: 2.2nF; C_0603_1608Metric; MPN C0603C222J3RACTU
C19: 1.8nF; C_0603_1608Metric; MPN C0603C182J5RACTU
D1, D2, D3, D4, D5, D6, D7: GRN; LED_0603_1608Metric; MPN 150060GS75000
L1: 8.2uH; L_Coilcraft_XxL4040; MPN XAL4040-822MEC
L2: 6.8uH; L_Coilcraft_XxL4030; MPN XAL4030-682MEC
L3: 3.3uH; L_Coilcraft_XxL4020; MPN XFL4020-332MEC
L4: 4.7uH; L_Coilcraft_XxL4020; MPN XFL4020-472MEC
Q1, Q2, Q3, Q4: Q_NMOS_GSD; SOT-23; MPN DMN65D8L-7
Q5: SI7232DN-T1-GE3; Si7232DN; MPN SI7232DN-T1-GE3
R1, R2, R31, R32, R33, R34: 20; R_0603_1608Metric; MPN CRCW060320R0JNEA
R3: 1k74; R_0603_1608Metric; MPN CRCW06031K74FKEA
R4: 24k9; R_0603_1608Metric; MPN CRCW060324K9FKEAC
R5: 21k; R_0603_1608Metric; MPN CRCW060321K0FKEAHP
R6, R13, R23, R24: 10K; R_0603_1608Metric; MPN RCS060310K0FKEA
R7: 21k1; R_0603_1608Metric; MPN CRCW060322K1FKEAHP
R10, R15, R19, R20: 10k; R_0603_1608Metric; MPN RCS060310K0FKEA
R11, R14: 12k1; R_0603_1608Metric; MPN CRCW060312K1FKEAHP
R12: 15k; R_0603_1608Metric; MPN CRCW060315K0FKEAHP
R16, R22: 8k2; R_0603_1608Metric; MPN RCS06038K20FKEA
R17: 127k; R_0603_1608Metric; MPN CRCW0603127KFKEAHP
R18, R21: 4k99; R_0603_1608Metric; MPN RCS06034K99FKEA
R25: 3k3; R_0603_1608Metric; MPN CRCW06033K30FKEAHP
R26: 4k22; R_0603_1608Metric; MPN CRCW06034K22FKEAHP
R27, R28, R29, R30: 10k; R_0603_1608Metric; MPN CRCW060310K0FKEA
TP1: 12v0; TestPoint_Pad_D1.0mm
TP2: 3v3; TestPoint_Pad_D1.0mm
TP3: 3v3 Aux; TestPoint_Pad_D1.0mm
TP4: 2v5; TestPoint_Pad_D1.0mm
TP5: 1v8; TestPoint_Pad_D1.0mm
TP6: 1v2; TestPoint_Pad_D1.0mm
TP7: 1v5; TestPoint_Pad_D1.0mm
U2: ADP5050ACPZ-R7; QFN-48_EP_7x7_Pitch0.5mm; MPN ADP5050ACPZ-R7

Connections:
+1V2: C21.1, L3.2, R18.1, R21.2, R28.1, TP6.1; also elsewhere on the board
+1V5: C22.1, L4.2, R16.1, R22.2, R30.1, TP7.1; also elsewhere on the board
+1V8: C14.2, L2.1, R11.1, R14.1, R27.1, TP5.1; also elsewhere on the board
+2V5: C9.2, L1.1, R7.1, R29.1, TP4.1
+3.3VA: R1.1, TP3.1; also elsewhere on the board
+3V3: R2.1, R31.1, R32.1, R33.1, R34.1, TP2.1; also elsewhere on the board
+12V: C1.2, C2.2, C4.2, C5.2, R3.1, R17.1, TP1.1, U2.4 (PVIN_3), U2.9 (PVIN_4), U2.24 (PVIN_2[0]), U2.25 (PVIN_2[1]), U2.35 (PVIN_1[1]), U2.36 (PVIN_1[0]); also elsewhere on the board
GND: C1.1, C2.1, C3.2, C4.1, C5.1, C6.2, C7.1, C9.1, C10.2, C11.1, C12.1, C14.1, C17.1, C18.2, C19.1, C20.2, C21.2, C22.2, D1.1 (K), D2.1 (K), D3.1 (K), Q1.2 (S), Q2.2 (S), Q3.2 (S), Q4.2 (S), Q5.1 (S), Q5.4 (S), R4.2, R6.2, R10.1, R13.1, R15.1, R19.2, R20.1, R23.1, R24.2, U2.2 (GND), U2.5 (EN_5), U2.6 (FB_5), U2.7 (VOUT_5), U2.8 (PVIN_5), U2.11 (GND), U2.30 (GND), U2.38 (SS12), U2.43 (SYNC/MODE), U2.47 (SS34), U2.49 (GND); also elsewhere on the board
unnamed: C3.1, U2.44 (VREG)
unnamed: C6.1, R5.1, U2.15 (COMP_4)
unnamed: C7.2, R5.2
unnamed: C8.1, L1.2, U2.10 (SW_4)
unnamed: C8.2, U2.12 (BST_4)
unnamed: C10.1, R12.1, U2.46 (COMP_3)
unnamed: C11.2, R12.2
unnamed: C12.2, U2.42 (VDD)
unnamed: C13.1, L2.2, U2.3 (SW_3)
unnamed: C13.2, U2.1 (BST_3)
unnamed: C15.1, U2.32 (BST_1)
unnamed: C15.2, L3.1, Q5.3 (D), U2.33 (SW_1[1]), U2.34 (SW_1[0])
unnamed: C16.1, U2.28 (BST_2)
unnamed: C16.2, L4.1, Q5.6 (D), U2.26 (SW_2[1]), U2.27 (SW_2[0])
unnamed: C17.2, R25.1
unnamed: C18.1, R25.2, U2.39 (COMP_1)
unnamed: C19.2, R26.1
unnamed: C20.1, R26.2, U2.22 (COMP_2)
unnamed: D1.2 (A), R1.2
unnamed: D2.2 (A), R2.2
unnamed: D3.2 (A), R3.2
unnamed: D4.1 (K), Q4.3 (D)
unnamed: D4.2 (A), R34.2
unnamed: D5.1 (K), Q1.3 (D)
unnamed: D5.2 (A), R31.2
unnamed: D6.1 (K), Q2.3 (D)
unnamed: D6.2 (A), R32.2
unnamed: D7.1 (K), Q3.3 (D)
unnamed: D7.2 (A), R33.2
unnamed: Q1.1 (G), R29.2
unnamed: Q2.1 (G), R27.2
unnamed: Q3.1 (G), R28.2
unnamed: Q4.1 (G), R30.2
unnamed: Q5.2 (G), U2.29 (DL2)
unnamed: Q5.5 (G), U2.31 (DL1)
unnamed: R4.1, U2.41 (RT)
unnamed: R6.1, R7.2, U2.16 (FB_4)
unnamed: R10.2, R11.2, U2.14 (EN_4)
unnamed: R13.2, R14.2, U2.45 (FB_3)
unnamed: R15.2, R16.2, U2.48 (EN_3)
unnamed: R17.2, R19.1, U2.37 (EN_1)
unnamed: R18.2, R20.2, U2.23 (EN_2)
unnamed: R21.1, R23.2, U2.40 (FB_1)
unnamed: R22.1, R24.1, U2.21 (FB_2)

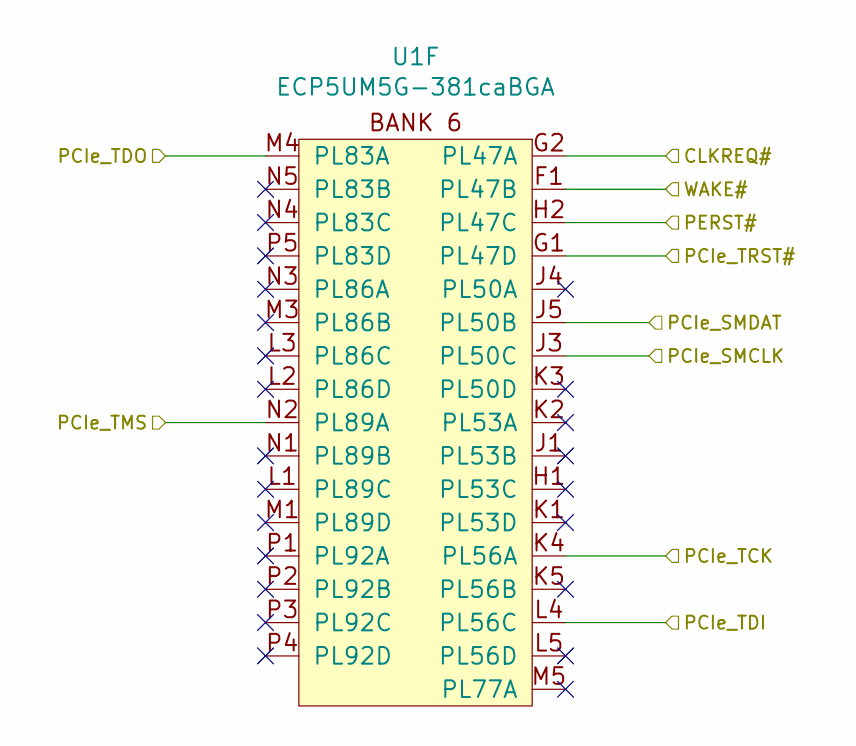
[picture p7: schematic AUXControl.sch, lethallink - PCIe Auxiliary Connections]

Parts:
U1: ECP5UM5G-381caBGA; 318caBGA; MPN LFE5UM5G-85F-8BG381I; DIGIKEY_PN 220-2112-ND

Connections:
/AUX Control/CLKREQ#: U1.G2 (PL47A); also elsewhere on the board
/AUX Control/PCIe_SMCLK: U1.J3 (PL50C); also elsewhere on the board
/AUX Control/PCIe_SMDAT: U1.J5 (PL50B); also elsewhere on the board
/AUX Control/PCIe_TCK: U1.K4 (PL56A); also elsewhere on the board
/AUX Control/PCIe_TDI: U1.L4 (PL56C); also elsewhere on the board
/AUX Control/PCIe_TDO: U1.M4 (PL83A); also elsewhere on the board
/AUX Control/PCIe_TMS: U1.N2 (PL89A); also elsewhere on the board
/AUX Control/PCIe_TRST#: U1.G1 (PL47D); also elsewhere on the board
/AUX Control/PERST#: U1.H2 (PL47C); also elsewhere on the board
/AUX Control/WAKE#: U1.F1 (PL47B); also elsewhere on the board

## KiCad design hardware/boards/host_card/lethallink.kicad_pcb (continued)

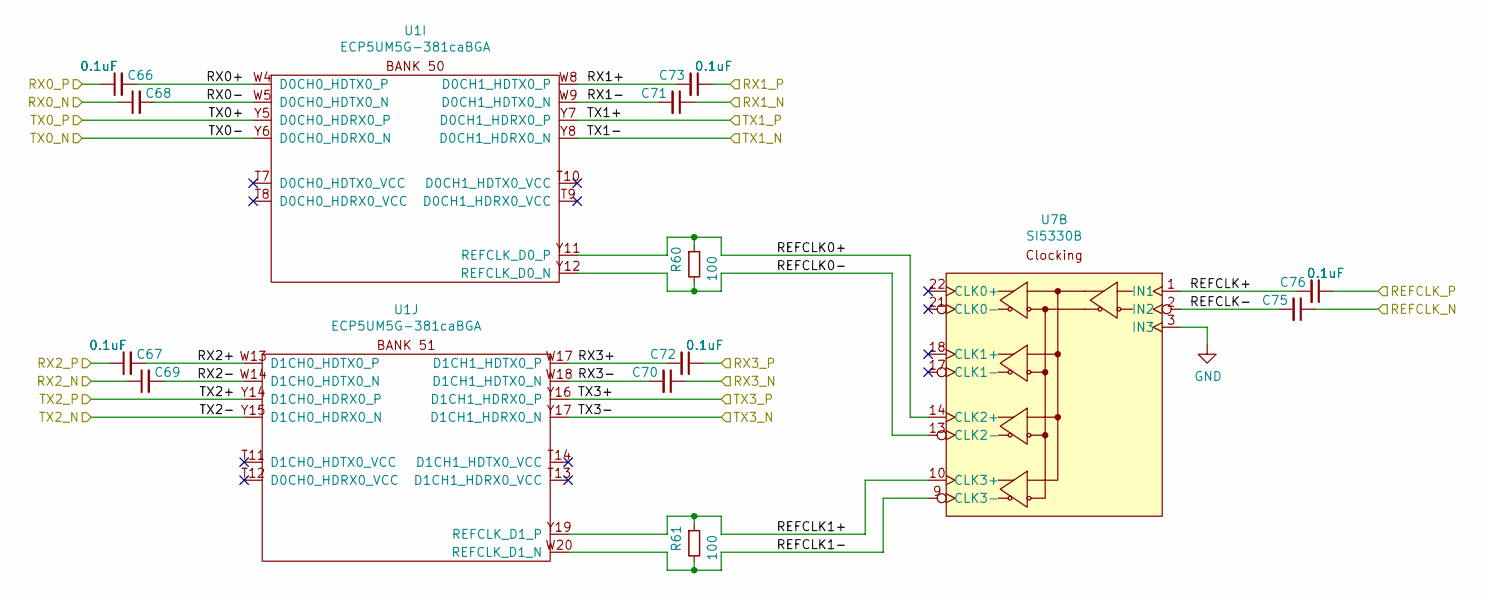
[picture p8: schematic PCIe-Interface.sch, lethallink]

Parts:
C66, C67, C68, C69, C70, C71, C72, C73, C75, C76: 0.1uF; C_0402_1005Metric; MPN C0402C104M8PACTU
R60, R61: 100; R_0402_1005Metric; MPN RCS0402100RFKED
U1: ECP5UM5G-381caBGA; 318caBGA
U7: SI5330B; VQFN-24-1EP_4x4mm_P0.5mm_EP2.45x2.45mm; MPN SI5330B-B00205-GM

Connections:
/PCIe Interface/REFCLK0+: R60.1, U1.Y11 (REFCLK_D0_P), U7.14 (CLK2+)
/PCIe Interface/REFCLK0-: R60.2, U1.Y12 (REFCLK_D0_N), U7.13 (CLK2-)
/PCIe Interface/REFCLK1+: R61.1, U1.Y19 (REFCLK_D1_P), U7.10 (CLK3+)
/PCIe Interface/REFCLK1-: R61.2, U1.W20 (REFCLK_D1_N), U7.9 (CLK3-)
/PCIe Interface/REFCLK+: C76.2, U7.1 (IN1)
/PCIe Interface/REFCLK-: C75.2, U7.2 (IN2)
/PCIe Interface/REFCLK_N: C75.1; also elsewhere on the board
/PCIe Interface/REFCLK_P: C76.1; also elsewhere on the board
/PCIe Interface/RX0+: C66.2, U1.W4 (D0CH0_HDTX0_P)
/PCIe Interface/RX0-: C68.2, U1.W5 (D0CH0_HDTX0_N)
/PCIe Interface/RX0_N: C68.1; also elsewhere on the board
/PCIe Interface/RX0_P: C66.1; also elsewhere on the board
/PCIe Interface/RX1+: C73.2, U1.W8 (D0CH1_HDTX0_P)
/PCIe Interface/RX1-: C71.2, U1.W9 (D0CH1_HDTX0_N)
/PCIe Interface/RX1_N: C71.1; also elsewhere on the board
/PCIe Interface/RX1_P: C73.1; also elsewhere on the board
/PCIe Interface/RX2+: C67.2, U1.W13 (D1CH0_HDTX0_P)
/PCIe Interface/RX2-: C69.2, U1.W14 (D1CH0_HDTX0_N)
/PCIe Interface/RX2_N: C69.1; also elsewhere on the board
/PCIe Interface/RX2_P: C67.1; also elsewhere on the board
/PCIe Interface/RX3+: C72.2, U1.W17 (D1CH1_HDTX0_P)
/PCIe Interface/RX3-: C70.2, U1.W18 (D1CH1_HDTX0_N)
/PCIe Interface/RX3_N: C70.1; also elsewhere on the board
/PCIe Interface/RX3_P: C72.1; also elsewhere on the board
/PCIe Interface/TX0_N: U1.Y6 (D0CH0_HDRX0_N); also elsewhere on the board
/PCIe Interface/TX0_P: U1.Y5 (D0CH0_HDRX0_P); also elsewhere on the board
/PCIe Interface/TX1_N: U1.Y8 (D0CH1_HDRX0_N); also elsewhere on the board
/PCIe Interface/TX1_P: U1.Y7 (D0CH1_HDRX0_P); also elsewhere on the board
/PCIe Interface/TX2_N: U1.Y15 (D1CH0_HDRX0_N); also elsewhere on the board
/PCIe Interface/TX2_P: U1.Y14 (D1CH0_HDRX0_P); also elsewhere on the board
/PCIe Interface/TX3_N: U1.Y17 (D1CH1_HDRX0_N); also elsewhere on the board
/PCIe Interface/TX3_P: U1.Y16 (D1CH1_HDRX0_P); also elsewhere on the board
GND: U7.3 (IN3); also elsewhere on the board

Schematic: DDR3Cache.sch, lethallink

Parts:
C74: 0.1uF; C_0603_1608Metric; MPN C0603C104M5RACTU
C83: 10nF; C_0402_1005Metric; MPN C0402C103M5RACTU
R8, R36: 50; R_0402_1005Metric; MPN FC0402E50R0BST1
R37, R62: 240; R_0603_1608Metric; MPN RNCF0603TKY250R
R58: 100; R_0402_1005Metric; MPN RCS0402100RFKED
U1: ECP5UM5G-381caBGA; 318caBGA; MPN LFE5UM5G-85F-8BG381I; DIGIKEY_PN 220-2112-ND
U4, U8: IS43TR16256B-125KBL; BGA-96_9.0x13.0mm_Layout2x3x16_P0.8mm; MPN IS43TR16256B-125KBL
X2: 100MHz; AX3; MPN AX3DCF1-100.0000

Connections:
/Boot Config/FPGA_DONE: U4.T2 (~RESET), U8.T2 (~RESET); also elsewhere on the board
/DDR3 Cache/A0: U1.K20 (PR44D), U4.N3 (A0), U8.N3 (A0)
/DDR3 Cache/A1: U1.J20 (PR44C), U4.P7 (A1), U8.P7 (A1)
/DDR3 Cache/A2: U1.K19 (PR44B), U4.P3 (A2), U8.P3 (A2)
/DDR3 Cache/A3: U1.J19 (PR44A), U4.N2 (A3), U8.N2 (A3)
/DDR3 Cache/A4: U1.K18 (PR41D), U4.P8 (A4), U8.P8 (A4)
/DDR3 Cache/A5: U1.F20 (PR38C), U4.P2 (A5), U8.P2 (A5)
/DDR3 Cache/A6: U1.K16 (PR29A), U4.R8 (A6), U8.R8 (A6)
/DDR3 Cache/A7: U1.J16 (PR20D), U4.R2 (A7), U8.R2 (A7)
/DDR3 Cache/A8: U1.J17 (PR20C), U4.T8 (A8), U8.T8 (A8)
/DDR3 Cache/A9: U1.H17 (PR20B), U4.R3 (A9), U8.R3 (A9)
/DDR3 Cache/A10: U1.H18 (PR20A), U4.L7 (A10/AP), U8.L7 (A10/AP)
/DDR3 Cache/A11: U1.H16 (PR17D), U4.R7 (A11), U8.R7 (A11)
/DDR3 Cache/A12: U1.G16 (PR17C), U4.N7 (A12/~BC), U8.N7 (A12/~BC)
/DDR3 Cache/A13: U1.G18 (PR17B), U4.T3 (A13), U8.T3 (A13)
/DDR3 Cache/A14: U1.F17 (PR17A), U4.T7 (A14), U8.T7 (A14)
/DDR3 Cache/A15: U1.F18 (PR14D), U4.M7 (A15/NC), U8.M7 (A15/NC)
/DDR3 Cache/BA0: U1.K17 (PR29B), U4.M2 (BA0), U8.M2 (BA0)
/DDR3 Cache/BA1: U1.C20 (PR35A), U4.N8 (BA1), U8.N8 (BA1)
/DDR3 Cache/BA2: U1.D19 (PR35B), U4.M3 (BA2), U8.M3 (BA2)
/DDR3 Cache/CK+: R8.1, U1.G19 (PR41A), U4.J7 (CK), U8.J7 (CK)
/DDR3 Cache/CK-: R36.1, U1.H20 (PR41B), U4.K7 (~CK), U8.K7 (~CK)
/DDR3 Cache/CKE0: U1.F19 (PR38B), U4.K9 (CKE)
/DDR3 Cache/CKE1: U1.G20 (PR38D), U8.K9 (CKE)
/DDR3 Cache/CLK+: R58.1, U1.L20 (PR47A), X2.4 (CLK)
/DDR3 Cache/CLK-: R58.2, U1.M20 (PR47B), X2.5 (~CLK)
/DDR3 Cache/DML0: U1.D17 (PR11B), U4.E7 (DML), U8.E7 (DML)
/DDR3 Cache/DMU0: U1.C18 (PR11A), U4.D3 (DMU), U8.D3 (DMU)
/DDR3 Cache/DQL0: U1.M19 (PR47D), U4.E3 (DQL0), U8.E3 (DQL0)
/DDR3 Cache/DQL1: U1.L16 (PR50A), U4.F7 (DQL1), U8.F7 (DQL1)
/DDR3 Cache/DQL2: U1.L18 (PR50C), U4.F2 (DQL2), U8.F2 (DQL2)
/DDR3 Cache/DQL3: U1.M18 (PR50D), U4.F8 (DQL3), U8.F8 (DQL3)
/DDR3 Cache/DQL4: U1.N18 (PR53C), U4.H3 (DQL4), U8.H3 (DQL4)
/DDR3 Cache/DQL5: U1.N17 (PR56A), U4.H8 (DQL5), U8.H8 (DQL5)
/DDR3 Cache/DQL6: U1.R17 (PR56D), U4.G2 (DQL6), U8.G2 (DQL6)
/DDR3 Cache/DQL7: U1.R16 (PR56C), U4.H7 (DQL7), U8.H7 (DQL7)
/DDR3 Cache/DQSL0+: U1.N16 (PR53A), U4.F3 (DQSL), U8.F3 (DQSL)
/DDR3 Cache/DQSL0-: U1.M17 (PR53B), U4.G3 (~DQSL), U8.G3 (~DQSL)
/DDR3 Cache/DQSU0+: U1.T19 (PR89A), U4.C7 (DQSU), U8.C7 (DQSU)
/DDR3 Cache/DQSU0-: U1.R18 (PR89B), U4.B7 (~DQSU), U8.B7 (~DQSU)
/DDR3 Cache/DQU0: U1.P19 (PR83C), U4.D7 (DQU0), U8.D7 (DQU0)
/DDR3 Cache/DQU1: U1.P18 (PR83D), U4.C3 (DQU1), U8.C3 (DQU1)
/DDR3 Cache/DQU2: U1.P20 (PR86A), U4.C8 (DQU2), U8.C8 (DQU2)
/DDR3 Cache/DQU3: U1.R20 (PR86B), U4.C2 (DQU3), U8.C2 (DQU3)
/DDR3 Cache/DQU4: U1.U20 (PR86D), U4.A7 (DQU4), U8.A7 (DQU4)
/DDR3 Cache/DQU5: U1.U19 (PR89C), U4.A2 (DQU5), U8.A2 (DQU5)
/DDR3 Cache/DQU6: U1.U18 (PR92A), U4.B8 (DQU6), U8.B8 (DQU6)
/DDR3 Cache/DQU7: U1.U17 (PR92B), U4.A3 (DQU7), U8.A3 (DQU7)
/DDR3 Cache/ODT0: U1.J18 (PR41C), U4.K1 (ODT)
/DDR3 Cache/ODT1: U1.T16 (PR77A), U8.K1 (ODT)
/DDR3 Cache/_1V8: C74.2, X2.1 (OE), X2.6 (VCC)
/DDR3 Cache/~CAS: U1.E19 (PR35D), U4.K3 (~CAS), U8.K3 (~CAS)
/DDR3 Cache/~CS0: U1.N19 (PR83A), U4.L2 (~CS)
/DDR3 Cache/~CS1: U1.N20 (PR83B), U8.L2 (~CS)
/DDR3 Cache/~RAS: U1.D20 (PR35C), U4.J3 (~RAS), U8.J3 (~RAS)
/DDR3 Cache/~WE: U1.E20 (PR38A), U4.L3 (~WE), U8.L3 (~WE)
GND: C74.1, C83.2, R37.2, R62.2, X2.3 (GND); also elsewhere on the board
unnamed: C83.1, R8.2, R36.2
unnamed: R37.1, U4.L8 (ZQ)
unnamed: R62.1, U8.L8 (ZQ)

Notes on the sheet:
~WE~ -> E20 ~RAS ~ -> D20 ODT1 -> T16 ODT0 -> J18 CKE1 -> G20 CKE0 -> F19 ~CAS ~ -> E19 BA2 -> D19 BA1 -> C20 BA0 -> K17 ADDR15 -> F18 ADDR14 -> F17 ADDR13 -> G18 ADDR12 -> G16 ADDR11 -> H16 ADDR10 -> H18 ADDR9 -> H17 ADDR8 -> J17 ADDR7 -> J16 ADDR6 -> K16 ADDR5 -> F20 ADDR4 -> K18 ADDR3 -> J19 ADD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
As Divined By Lattice Diamond
TODO: DDR3 Termination

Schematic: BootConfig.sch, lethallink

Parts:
C54: 0.1uF; C_0603_1608Metric; MPN C0603C104M5RACTU
C55, C56: 15pF; C_0603_1608Metric; MPN C0603C150J5GACTU
D8: BLU; LED_0603_1608Metric; MPN 150060BS75000
D9: RED; LED_0603_1608Metric; MPN 150060RS75000
D10: PNK; LED_0603_1608Metric; MPN OSK40603C1E
J3: Conn_02x05_Odd_Even; FTSH-105-01-L-DV-K-TR; MPN FTSH-105-01-L-DV-K-TR
J4: Conn_02x04_Odd_Even; FTSH-105-01-L-DV-K-TR; MPN FTSH-105-01-L-DV-K-TR
J7: Conn_02x04_Odd_Even; PinHeader_2x04_P2.54mm_Vertical
Q6, Q7: Q_NMOS_GSD; SOT-23; MPN DMN65D8L-7
R9: 1k; R_0603_1608Metric; MPN CRCW06031K00FKEAHP
R38, R39, R40, R41, R43, R44, R45, R46, R48, R49, R50, R51, R54: 10k; R_0603_1608Metric; MPN CRCW060310K0FKEA
R42: 50; R_0603_1608Metric; MPN CRCW060350R0FKEA
R47: 4k7; R_0603_1608Metric; MPN RCS06034K70FKEA
R52: 6k04; R_0603_1608Metric; MPN RCS06036K04FKEA
R53: 200; R_0603_1608Metric; MPN RCS0603200RFKEA
R55: 1k; R_0402_1005Metric; MPN RCS04021K00FKED
SW2: RESET; SW_Push_1P1T_NO_CK_KMR2; MPN KMR241NG ULC LFS
U1: ECP5UM5G-381caBGA; 318caBGA; MPN LFE5UM5G-85F-8BG381I; DIGIKEY_PN 220-2112-ND
U3: CYUSB3014; BGA-121_11x11_10.0x10.0mm; MPN CYUSB3014-BZXI; DIGIKEY_PN 428-3130-ND
U5: 128MiB; WSON-8-1EP-6.0x8.0mm; MPN W25N01GVZEIG TR
Y1: 19.2MHz; Crystal_SMD_Abracon_ABM10-4Pin_2.5x2.0mm; MPN ABM10-19.200MHZ-D30-T3

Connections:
+1V8: R55.1; also elsewhere on the board
+3V3: J3.1, J4.4, R9.1, R38.1, R39.1, R40.1, R41.1, R43.1, R44.1, R45.1, R46.1, R47.1, R48.1, R50.1, R51.1; also elsewhere on the board
/Boot Config/FPGA_CLK: J7.7; also elsewhere on the board
/Boot Config/FPGA_DI: J7.5; also elsewhere on the board
/Boot Config/FPGA_DO: J7.3; also elsewhere on the board
/Boot Config/FPGA_DONE: R49.2, U1.Y3 (DONE); also elsewhere on the board
/Boot Config/FPGA_TDO: U1.V4 (TDO), U3.E7 (TDI)
/Boot Config/TCK: J3.4, R39.2, U1.T5 (TCK), U3.F6 (TCK)
/Boot Config/TDI: J3.8, R41.2, U1.R5 (TDI)
/Boot Config/TDO: J3.6, R40.2, U3.C10 (TDO)
/Boot Config/TMS: J3.2, R38.2, U1.U5 (TMS), U3.E8 (TMS)
/Boot Config/XTAL+: C56.2, U3.C6 (XTAL_IN), Y1.3
/Boot Config/XTAL-: C55.2, U3.C7 (XTAL_OUT), Y1.1
/Boot Config/~FPGA_CS: J7.1; also elsewhere on the board
/Boot Config/~INIT: D9.1 (K), J4.1, U1.V3 (~INIT)
/Boot Config/~PHY_INT: U3.L8 (INT#); also elsewhere on the board
/Boot Config/~PHY_RESET: R54.1, U1.T3 (PB18A/WRITEN); also elsewhere on the board
/Boot Config/~RESET: C54.2, D10.1 (K), J3.10, J4.2, R50.2, SW2.1, U1.W3 (~PROGRAM), U3.B11 (TRST#)
GND: C54.1, C55.1, C56.1, J3.3, J3.5, J3.9, J4.3, Q6.2 (S), Q7.2 (S), R52.2, R53.2, SW2.2, U1.R4 (CFG_2), U1.U4 (CFG_0), U3.B2 (FSLC[0]), U3.B4 (FSLC[1]), U3.E6 (FSLC[2]), Y1.2, Y1.4; also elsewhere on the board
unnamed: D8.1 (K), Q6.3 (D)
unnamed: D8.2 (A), R47.2
unnamed: D9.2 (A), R48.2
unnamed: D10.2 (A), R51.2
unnamed: J4.5, J7.6, R46.2, U1.V2 (PB11A/D1/MISO/IO1), U5.5 (DI/IO0)
unnamed: J4.6, R43.2, U1.Y2 (PB9B/D2/IO2), U5.3 (~WP~/IO2)
unnamed: J4.7, J7.8, R42.1, U5.6 (CLK)
unnamed: J4.8, J7.4, R44.2, U1.W2 (PB11B/D0/MOSI/IO2), U5.2 (DO/IO1)
unnamed: J4.9, R45.2, U1.W1 (PB9A/D3/IO3), U5.7 (~HOLD~/IO3)
unnamed: J4.10, J7.2, U1.R2 (PB15A/HOLDN/DI/BUSY/CSSPIN/CEN), U5.1 (~CS)
unnamed: Q6.1 (G), R49.1
unnamed: Q7.1 (G), R54.2
unnamed: Q7.3 (D), R55.2, U3.C5 (RESET#)
unnamed: R9.2, U1.T4 (CFG_1)
unnamed: R42.2, U1.U3 (CCLK)
unnamed: R52.1, U3.C8 (R_USB2)
unnamed: R53.1, U3.B3 (R_USB3)

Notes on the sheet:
CFG[0..2] should be 0 1 0 for SPI primary.
I *think* this is correct?
SWD/JTAG Pinout: 01 - 3v3 02 - TMS 03 - GND 04 - TCK 05 - GND 06 - TDO 07 - NC 08 - TDI 09 - GND 10 - ~PROGRAM/RESET
FSLC[0..2] Set to 0 0 0 for 19.2MHz Crystal input.
SPI Flash Pinout 01 - ~INIT~ 02 - ~PROGRAM~ 03 - GND 04 - 3v3 05 - DI/IO0 06 - ~WP~/IO2 07 - CLK 08 - DO/IO1 09 - ~HOLD~/IO3 10 - ~CS~
FPGA SPI flash USB PHY jumper. Close to enable DFU for gateware

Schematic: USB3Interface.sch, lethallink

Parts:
C39: 0.1uF; C_0603_1608Metric; MPN C0603C104M5RACTU
C77, C78: 0.1uF; C_0402_1005Metric; MPN C0402C104M8PACTU
D11: RClamp3324P; MPN RCLAMP3324P.TNT
D12: RClamp0512; MPN RCLAMP0512TQTCT
J2: USB3_Micro_B_Amphenol; MPN GSB343K33HR; DIGIKEY_PN GSB343K33HRCT-ND
J5: Conn_02x04_Odd_Even; FTSH-105-01-L-DV-K-TR; MPN FTSH-105-01-L-DV-K-TR
R35: 1M; R_0603_1608Metric; MPN CRCW06031M00FKEA
R59: 1k; R_0402_1005Metric; MPN RCS04021K00FKED
U1: ECP5UM5G-381caBGA; 318caBGA; MPN LFE5UM5G-85F-8BG381I; DIGIKEY_PN 220-2112-ND
U3: CYUSB3014; BGA-121_11x11_10.0x10.0mm; MPN CYUSB3014-BZXI; DIGIKEY_PN 428-3130-ND
U6: 128MiB; WSON-8-1EP-6.0x8.0mm; MPN W25N01GVZEIG

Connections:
+1V8: R59.1; also elsewhere on the board
+3V3: J5.4; also elsewhere on the board
/Boot Config/FPGA_CLK: J5.7, U3.D4 (GPIO[53]), U6.6 (CLK); also elsewhere on the board
/Boot Config/FPGA_DI: J5.5, U3.D5 (GPIO[56]), U6.5 (DI/IO0); also elsewhere on the board
/Boot Config/FPGA_DO: J5.8, U3.C2 (GPIO[55]), U6.2 (DO/IO1); also elsewhere on the board
/Boot Config/~FPGA_CS: U3.C4 (GPIO[57]); also elsewhere on the board
/Boot Config/~PHY_INT: U1.D2 (PL38C); also elsewhere on the board
/Boot Config/~PHY_RESET: J5.2; also elsewhere on the board
/IC Power/VBUS: J2.1 (VBUS); also elsewhere on the board
/USB3 Interface/ALE: U1.E1 (PL38D), U3.K5 (GPIO[27])
/USB3 Interface/D+: D12.2, J2.3 (D_P), U3.A9 (D_P)
/USB3 Interface/D-: D12.1, J2.2 (D_N), U3.A10 (D_N)
/USB3 Interface/DQ0: U1.A4 (PL11A), U3.F10 (GPIO[00])
/USB3 Interface/DQ1: U1.C5 (PL11D), U3.F9 (GPIO[01])
/USB3 Interface/DQ2: U1.E4 (PL17A), U3.F7 (GPIO[02])
/USB3 Interface/DQ3: U1.B4 (PL14B), U3.G10 (GPIO[03])
/USB3 Interface/DQ4: U1.D5 (PL17B), U3.G9 (GPIO[04])
/USB3 Interface/DQ5: U1.C3 (PL17C), U3.F8 (GPIO[05])
/USB3 Interface/DQ6: U1.A3 (PL14C), U3.H10 (GPIO[06])
/USB3 Interface/DQ7: U1.C4 (PL14A), U3.H9 (GPIO[07])
/USB3 Interface/DQ8: U1.B3 (PL14D), U3.J10 (GPIO[08])
/USB3 Interface/DQ9: U1.C1 (PL38A), U3.J9 (GPIO[09])
/USB3 Interface/DQ10: U1.A2 (PL35A), U3.K11 (GPIO[10])
/USB3 Interface/DQ11: U1.B1 (PL35B), U3.L10 (GPIO[11])
/USB3 Interface/DQ12: U1.B2 (PL35C), U3.K10 (GPIO[12])
/USB3 Interface/DQ13: U1.C2 (PL35D), U3.K9 (GPIO[13])
/USB3 Interface/DQ14: U1.E3 (PL20B), U3.J8 (GPIO[14])
/USB3 Interface/DQ15: U1.D3 (PL17D), U3.G8 (GPIO[15])
/USB3 Interface/OE: U1.E2 (PL44D), U3.J7 (GPIO[19])
/USB3 Interface/PMODE_0: R59.2, U3.G4 (GPIO[30])
/USB3 Interface/PMODE_1: U3.H4 (GPIO[31])
/USB3 Interface/PSSTX+: C77.1, U3.A5 (SSTX_P)
/USB3 Interface/PSSTX-: C78.1, U3.A6 (SSTX_N)
/USB3 Interface/SSRX+: D11.2, J2.7 (SSTX_P), U3.A4 (SSRX_P)
/USB3 Interface/SSRX-: D11.1, J2.6 (SSTX_N), U3.A3 (SSRX_N)
/USB3 Interface/SSTX+: C77.2, D11.4, J2.10 (SSRX_P)
/USB3 Interface/SSTX-: C78.2, D11.3, J2.9 (SSRX_N)
/USB3 Interface/WE_D: U1.D1 (PL38B), U3.K7 (GPIO[18])
GND: C39.1, D11.GND, D12.GND, J2.5 (GND), J2.8 (GND), J5.1, J5.3, R35.2, U3.L4 (GPIO[32]); also elsewhere on the board
unnamed: C39.2, J2.11 (SHEILD), R35.1
unnamed: J5.6, U6.3 (~WP~/IO2)
unnamed: J5.9, U6.7 (~HOLD~/IO3)
unnamed: J5.10, U3.C1 (GPIO[54]), U6.1 (~CS)

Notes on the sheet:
SPI Flash Pinout 01 - GND 02 - ~PHY_RESET~ 03 - GND 04 - 3v3 05 - DI/IO0 06 - ~WP~/IO2 07 - CLK 08 - DO/IO1 09 - ~HOLD~/IO3 10 - ~CS~
PHY Boot config 0 0 X - Sync ADMux 1 0 X - Async ADMux 1 1 X - USB 1 X 0 - SPI, USB On failure

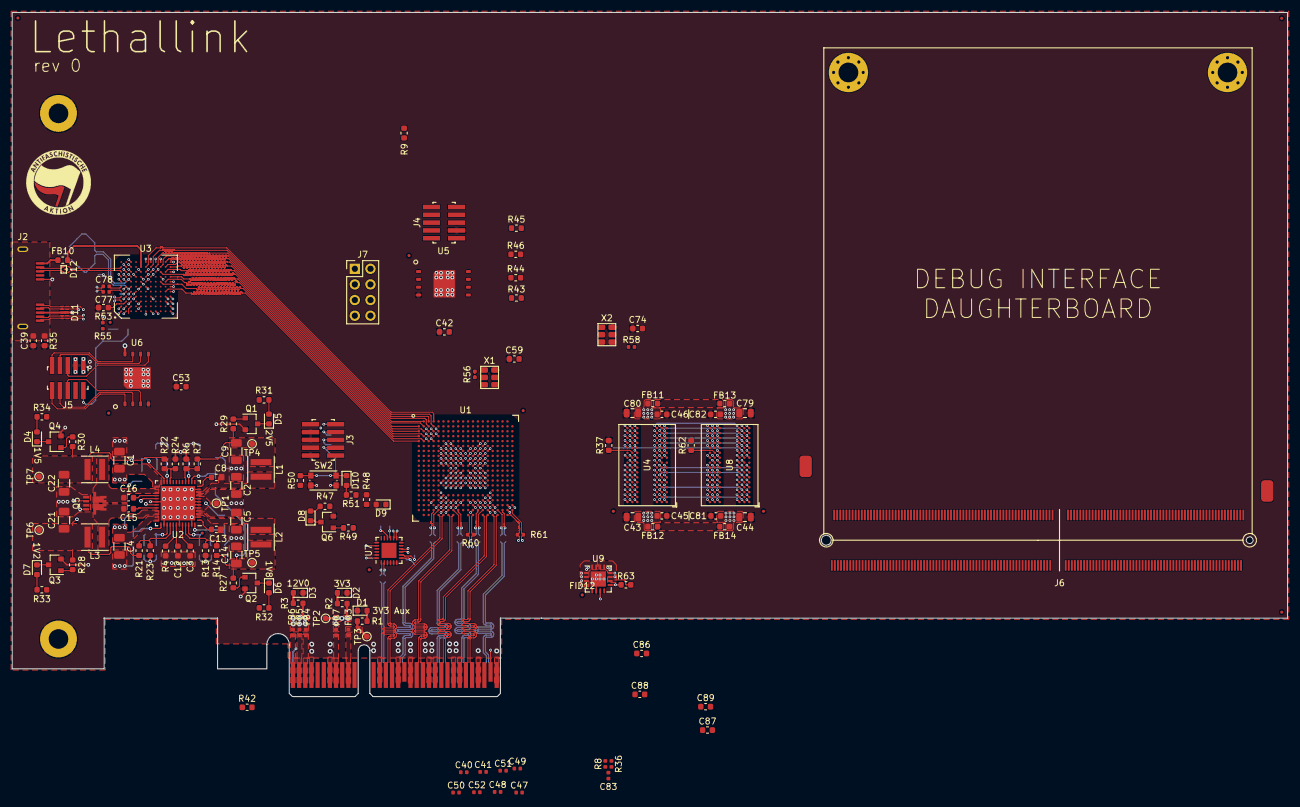
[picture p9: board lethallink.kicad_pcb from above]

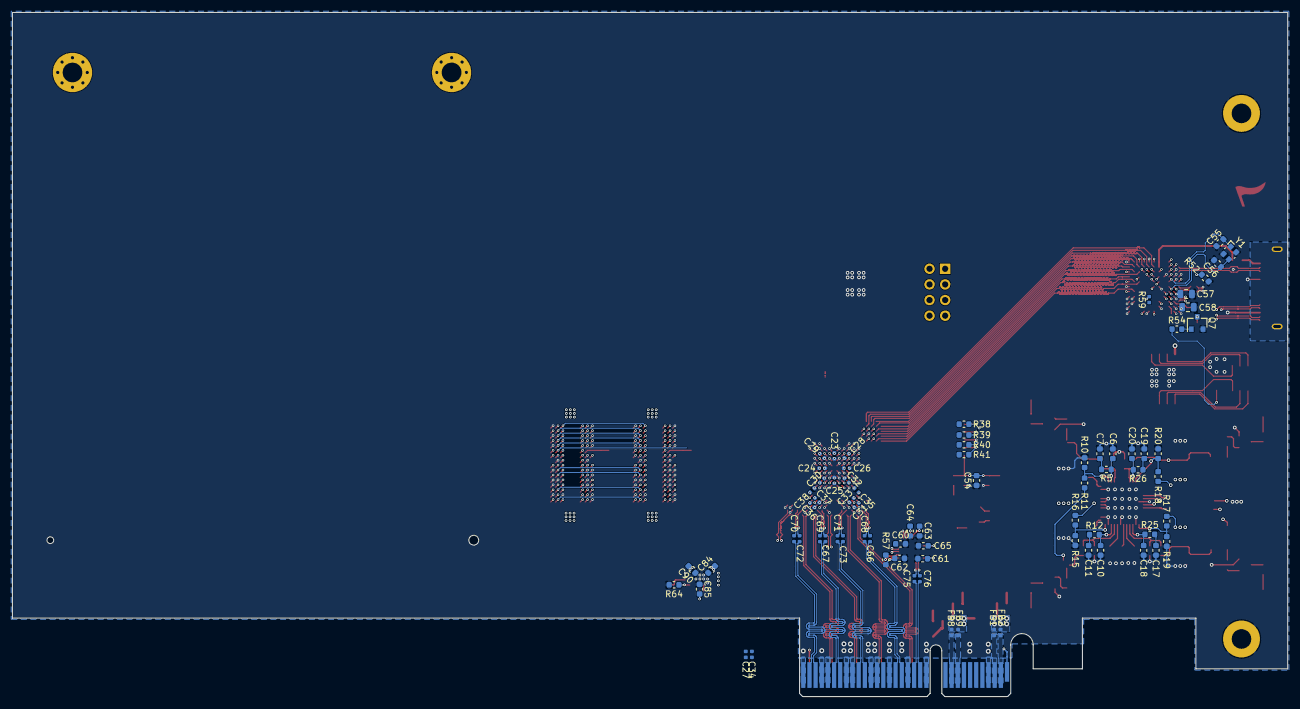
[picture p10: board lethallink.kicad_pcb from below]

Board: 6 copper layers, 207.2 x 111.1 mm, 231 parts (75 on the bottom side), 237 nets.

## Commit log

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2020-05-31 Added and hooked up the nested schematic for the FPGA PCIe interface
    [PCIe-Interface.sch, lethallink.kicad_pcb, lethallink.sch]
2020-06-01 Added some more schematics for blocking things out, and tweaked the GND fingers on the PCIe edge a bit
    [AUXControl.sch, BootConfig.sch, DebugInterface.sch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]
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2020-06-02 A bit of work on the power supply, the values still need to be calculated, but all the passives and such should be there
    [PowerSupply.sch]
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2020-06-03 Did some annotation and fixed the FPGA bank that was accidentally labled as the cypress part
    [BootConfig.sch, DebugInterface.sch, ExternalInterface.sch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]
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2020-06-06 Lots of small updates, getting values specified for parts, switched the BJT to NFETs
    [AUXControl.sch, BootConfig.sch, DebugInterface.sch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]
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2020-06-11 flipped ome parts to clean up how the lables were placed
    [PowerSupply.sch]
2020-06-14 Updated the powersupply and schematic frames. Ran all the numbers for the passives for the supply
    [AUXControl.sch, BootConfig.sch, DebugInterface.sch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]
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2020-06-14 Some strugglebusting on getting the ERC errors cleaned up a bit
    [AUXControl.sch, BootConfig.sch, DebugInterface.sch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]
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2020-06-14 Switched out the inductor footprints to ones that now have 3d models
    [PowerSupply.sch]
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2020-06-14 Imported the parts onto the board, and group things roughly by functional group in preperation to route
    [lethallink.kicad_pcb]
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2020-06-14 Upped the schematic frame size from A4 to A3 to allow for some more breathing room, it was getting stuff in the powersupply schematic
    [AUXControl.sch, BootConfig.sch, DebugInterface.sch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]
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2020-06-14 Updated the schematics and PCB to bring the initial bootup config DIP switch for the FPGA into it and also ensured that the FPGA had VCCIO8 tied to 3v3 for proper config voltages
    [BootConfig.sch, ICPower.sch, PowerSupply.sch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]
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2020-06-14 Added the SPI Flash for the gateware, softcore firmware, and USB controller firmware, all the firmware really.
    [BootConfig.sch, ICPower.sch, lethallink.kicad_pcb]
2020-06-14 Got a fair bit of the initial layout done for the power supply
    [ICPower.sch, PowerSupply.sch, lethallink.kicad_pcb]
2020-06-14 Upped the priority on the PSU pours to prevent them from getting drowned by the board-wide gnd pours
    [lethallink.kicad_pcb]
2020-06-15 Some more routing and placing of the PSU, lots to do still but it's progressing nicely
    [lethallink.kicad_pcb]
2020-06-15 Lots more place and routing done for the power supply, only the feeback and enable voltage deviders left to go, along with joining the two halfs with a common +12v pour
    [PowerSupply.sch, lethallink.kicad_pcb]
2020-06-15 Completed the PSU routing, not happy with some of the traces, might want to swap channels 3 and 4 to make the power-on sequence a bit better in terms of traces needing to be run
    [lethallink.kicad_pcb]
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2020-06-15 Fixed the revision numbers
    [AUXControl.sch, BootConfig.sch, DebugInterface.sch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]
2020-06-15 Playing around with some of the PCIe power input stuff, not happy with it, I'll rip it up and try again some other time
    [lethallink.kicad_pcb]
2020-06-15 Moving some things around trying to figure out where they should roughly go, Also added some isolated earth pours for the USB sheild
    [lethallink.kicad_pcb, lethallink.sch]
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2020-06-16 In an AHDH fuled stupor I made a bunch of changes, only the last of which I recall, which would be adding fiducials
    [ICPower.sch, MechanicalGraphic.sch, USB3Interface.sch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]
2020-06-16 Added some basic pour keepouts to help manage the pours under the BGA parts
    [lethallink.kicad_pcb]
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2020-06-16 Worked on a bit of the power side for the DDR3 Cache
    [ICPower.sch, LPDDR3Cache.sch, lethallink.kicad_pcb]
2020-06-16 Fixed the name of the DDR3 cache schematic, as we're not using LPDDR3
    [DDR3Cache.sch, lethallink.sch]
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2020-06-16 Added a secondary SPI flash for the USB PHY Firmware. Yes it's overkill but it'll be fine. I'll use it to like, store configuration data or something
    [BootConfig.sch, ICPower.sch, USB3Interface.sch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]
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2020-06-17 Added a bunch of stuff having to do with JTAG and the FPGA flash / bring up
    [BootConfig.sch, DDR3Cache.sch, USB3Interface.sch]
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2020-06-17 Added a debounce cap to the reset switch, as well as selected the reset switch itself, also added the needed pull-down resistors for the USB PHY
    [BootConfig.sch]
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2020-06-17 Annotated the schematics and updated the PCB with the new imported parts
    [BootConfig.sch, lethallink.kicad_pcb]
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2020-06-17 Resized some nested schematics and pulled the GPIF II interrupt line out from the boot config block into the USB 3 interface
    [BootConfig.sch, USB3Interface.sch, lethallink.sch]
2020-06-17 Updated the PCB with the new parts for PHY reset logic and added another fiducial for the other SPI flash
    [ICPower.sch, MechanicalGraphic.sch, PowerSupply.sch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]
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2020-06-17 Added headers for the SPI flash for both the FPGA and the PHY
    [BootConfig.sch, DDR3Cache.sch, USB3Interface.sch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]
2020-06-17 Fixed the VIO4 rail of the USB PHY to be 3v3 not 1v8
    [ICPower.sch]
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2020-06-17 Hooked up most of the GPIF II bus to the the FPGA
    [USB3Interface.sch, lethallink.kicad_pcb]
2020-06-17 Moved the power supply around and poked some of the IC lables
    [lethallink.kicad_pcb]
2020-06-17 Added a clock fanout buffer for the PCIe REFCLOCK to connect to the FPGAs SERDES banks
    [ICPower.sch, PCIe-Interface.sch, lethallink.kicad_pcb]
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2020-06-18 Added missing bypass caps for the VCCO rails for the clock buffer
    [ICPower.sch, PCIe-Interface.sch, lethallink.kicad_pcb]
2020-06-18 Fixed up the clearences on the pours
    [lethallink.kicad_pcb]
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2020-06-18 Moving banks around and rotated the FPGA to try and give the SERDES channels the best routing to the PCIe connector
    [DDR3Cache.sch, ExternalInterface.sch, USB3Interface.sch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]
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2020-06-18 Moved some things around swapping the DDR from banks 7 and 8 to banks 2 and 3, and moved the GPIFF 2 stuff to bank 7 to stop them from crossing over
    [DDR3Cache.sch, ExternalInterface.sch, USB3Interface.sch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]
2020-06-18 Moved some more banks around to try and keeps things from crossing over as much as possible
    [AUXControl.sch, ExternalInterface.sch, USB3Interface.sch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]
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2020-06-19 Added the debug module connector (SODIMM 260), it's not hooked up to anything yet
    [DebugInterface.sch, ICPower.sch, lethallink.kicad_pcb]
2020-06-19 Moved the host card board files into its own subdirectory to allow for the debug modules to also be in the boards / gerbers directory without a massive mess
    [AUXControl.sch, BootConfig.sch, DDR3Cache.sch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]
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2020-06-19 Expanded the board length to 254mm and fixed the ground pours. thinking expanding the DM module length to 80 mm
    [lethallink.kicad_pcb]
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2020-06-19 Fixed the pin table
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2020-06-21 Fixed up the consistancy of value naming, 100nF -> 0.1uF. Added the caps for the USB SSRX lines, moved the Ferrite for VBUS to fix a net naming issue
    [ICPower.sch, USB3Interface.sch, lethallink.kicad_pcb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]
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2020-06-24 Fixed the pour keepout for the DDR3 modules
    [lethallink.kicad_pcb]
2020-06-24 Fixed the missing address lines from the second DRAM module
    [DDR3Cache.sch]
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2020-07-05 Fixed / updated the ECP5 symbol for the ECP5UM5G-85K
    [AUXControl.sch, BootConfig.sch, DDR3Cache.sch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]
2020-07-05 Fixed the missing bus connections to the FPGA for the USB3 PHY, and updated the PCB
    [USB3Interface.sch, lethallink.kicad_pcb]
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2020-07-05 Fixed some traces that were munged w/ the PR
    [lethallink.kicad_pcb]
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2020-08-23 Broke out the DDR3 modules and added the 0.75V LDO for the VREFCA and VREFDQ lines for each of the DDR3 modules
    [BootConfig.sch, DDR3Cache.sch, ExternalInterface.sch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]
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
